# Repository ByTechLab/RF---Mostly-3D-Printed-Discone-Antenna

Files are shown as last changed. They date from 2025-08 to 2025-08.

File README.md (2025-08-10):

<div align="center">
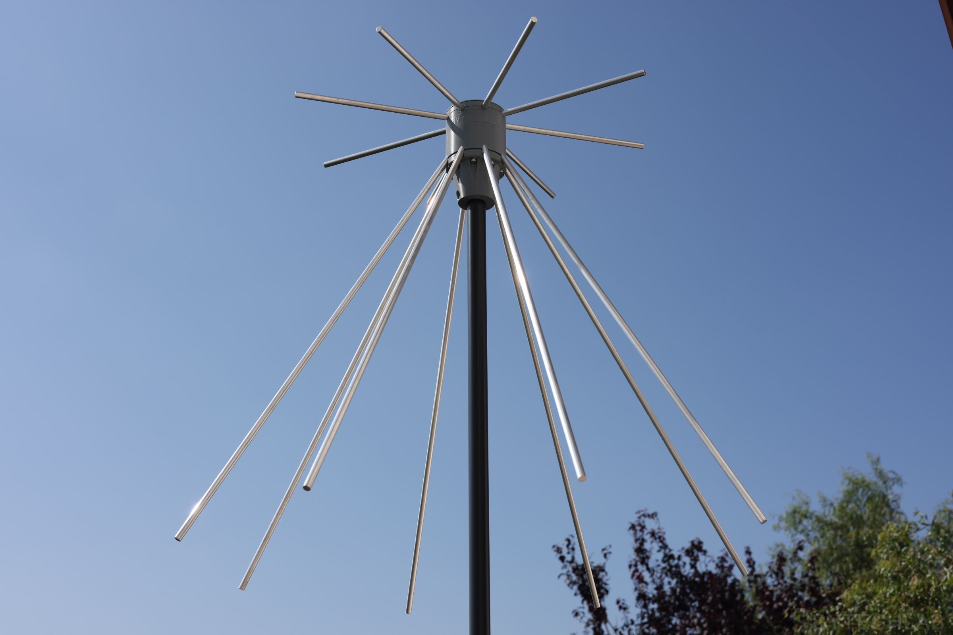
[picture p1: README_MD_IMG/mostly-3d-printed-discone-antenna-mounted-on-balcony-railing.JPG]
project photo
    
</div>

Mostly 3D printed discone antenna for Software Definied Radio.

### Read more at BYTECHLAB:

<table style="width: 100%; border: none;" cellspacing="0" cellpadding="0" border="0">
  <tr>
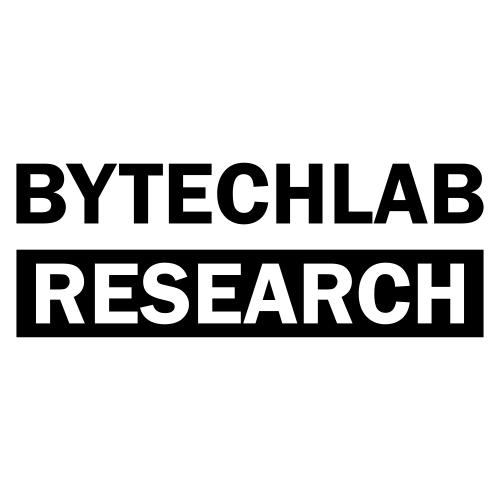
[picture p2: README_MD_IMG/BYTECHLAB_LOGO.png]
    <td></td>
    <td>https://bytechlab.com/2018/05/mostly-3d-printed-discone-antenna/</td>
  </tr>
</table>

## License
Software \ Firmware:



Hardware \ Hardware design files \ Hardware documentation:

[][cc-by-nc-sa]

[Creative Commons Attribution-NonCommercial-ShareAlike 4.0 International License][cc-by-nc-sa].

[][cc-by-nc-sa]

[cc-by-nc-sa]: http://creativecommons.org/licenses/by-nc-sa/4.0/
[cc-by-nc-sa-image]: https://licensebuttons.net/l/by-nc-sa/4.0/88x31.png
[cc-by-nc-sa-shield]: https://img.shields.io/badge/License-CC%20BY--NC--SA%204.0-lightgrey.svg

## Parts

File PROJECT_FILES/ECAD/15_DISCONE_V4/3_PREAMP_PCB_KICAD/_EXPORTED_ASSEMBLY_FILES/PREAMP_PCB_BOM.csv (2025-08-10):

Reference | Qty | Manufacturer | Manufacturer Part Number | SCH_FOOTPRINT
C1,C4 | 2 | Wurth Elektronik | 885012206052 | 0603
C2,C3 | 2 | Kemet | C0603X104K1RACTU | 0603
C5,C6 | 2 | Murata | GRM1885C1H103JA01D | 0603
GDT1,GDT2 | 2 | Littelfuse | CG775MS | 2.8x3.5mm
J1,J2 | 2 | Adam Tech | RF2-143-T-17-50-G | SMA_EDGE
L1 | 1 | Murata Electronics | LQW18ANR39J00D | 0603
L2,L3 | 2 | Coilcraft | WA8514-AE | 4.4x2mm
R1 | 1 | Panasonic | ERJ-3EKF1001V | 0603
TVS1,TVS2 | 2 | Bourns | CGA0603MLC-05E | 0603
U1 | 1 | ON Semiconductor | NCV8163ASN300T1G | SOT23-5
U2 | 1 | Mini-Circuits | PMA-5452+ | DQ849

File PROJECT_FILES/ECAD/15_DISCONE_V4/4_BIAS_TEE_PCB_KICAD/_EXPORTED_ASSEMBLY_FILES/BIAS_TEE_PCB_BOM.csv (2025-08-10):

Reference | Qty | Manufacturer | Manufacturer Part Number | SCH_FOOTPRINT
C1 | 1 | Kemet | C0603X104K1RACTU | 0603
C2 | 1 | Wurth Elektronik | 885012206052 | 0603
C3,C4 | 2 | Murata | GRM155R71H104KE14D | 0402
C5 | 1 | Murata | GRM1885C1H103JA01D | 0603
F1 | 1 | BEL Fuse | 0ZCJ0025AF2E | 1206
GDT1 | 1 | Littelfuse | CG775MS | 2.8x3.5mm
J1 | 1 | GCT | USB4105-GF-A | SMD USBC
J2 | 1 | Amphenol RF | 132366 | SMA_EDGE
J3 | 1 | Adam Tech | RF2-143-T-17-50-G | SMA_EDGE
L1 | 1 | Coilcraft | WA8514-AE | 4.4x2mm
R1,R2 | 2 | Panasonic | ERJ-2RKF5101X | 0402
R3,R4 | 2 | Panasonic | ERJ-2RKF1004X | 0402
TVS1 | 1 | Bourns | CGA0603MLC-05E | 0603

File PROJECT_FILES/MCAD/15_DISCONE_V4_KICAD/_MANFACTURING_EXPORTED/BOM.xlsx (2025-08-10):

Item | Filename | Thumbnail | BOM Structure | Unit QTY | QTY
1 | 3DP_ASA_Top_Disc_Bottom_Half.ipt |  | Normal | Each | 1
2 | CUT_COPPER_Top_Disc_1,5mm_Connecting_Wire.ipt |  | Normal | Each | 8
3 | ISO 7380-1 - M4 x 10.ipt |  | Purchased | Each | 16
4 | CUT_ALU_10x284mm_Rod.ipt |  | Normal | Each | 8
5 | 3DP_ASA_Rod_End_Cap.ipt |  | Normal | Each | 16
6 | 3DP_ASA_Top_Disc_Top_Half.ipt |  | Normal | Each | 1
7 | 3DP_ASA_Bottom_Cone_Bottom_Half.ipt |  | Normal | Each | 1
8 | 3DP_ASA_Bottom_Cone_Top_Half.ipt |  | Normal | Each | 1
9 | CUT_ALU_10x800mm_Rod.ipt |  | Normal | Each | 8
10 | CUT_COPPER_Bottom_Cone_1,5mm_Connecting_Wire.ipt |  | Normal | Each | 8
11 | CUT_FR4_Bottom_Cone_PCB.ipt |  | Purchased | Each | 1
12 | COTS_CarbonCenter_Fiberglass_30x28x2000mm_Pipe.ipt |  | Normal | Each | 1
13 | 3DP_ASA_Mast_Mount.ipt |  | Normal | Each | 1
14 | 3DP_ASA_Cone_and_Disc_Mount.ipt |  | Normal | Each | 1
15 | DIN 934 - M5 x 0,8.ipt |  | Purchased | Each | 15
16 | DIN 125 - A 5,3.ipt |  | Purchased | Each | 22
17 | COTS_GENERIC_DIN 912 - M5x80.ipt |  | Purchased | Each | 8
18 | COTS_Dremec_8G206M5X40_M5x40_Nylon_Screw.ipt |  | Purchased | Each | 8
19 | COTS_GENERIC_DIN 912 - M5x60.ipt |  | Purchased | Each | 1
20 | 3DP_ASA_Balcony_Mounting_Clamp_Back.ipt |  | Normal | Each | 3
21 | 3DP_ASA_Balcony_Mounting_Clamp_Front.ipt |  | Normal | Each | 3
22 | 3DP_ASA_Balcony_Mounting_Clamp_Mid.ipt |  | Normal | Each | 3
23 | COTS_GENERIC_DIN 912 - M5x120.ipt |  | Purchased | Each | 6
24 | COTS_GENERIC_Balcony_Railing.ipt |  | Normal | Each | 1
25 | 3DP_ASA_Preamp_Case_Bottom.ipt |  | Normal | Each | 1
26 | COTS_BOSSARD_1386867_M3_Insert.ipt |  | Normal | Each | 8
27 | 3DP_ASA_Preamp_Case_Top.ipt |  | Normal | Each | 1
28 | DIN 125 - A 3,2.ipt |  | Purchased | Each | 8
29 | ISO 7380-1 - M3 x 16.ipt |  | Purchased | Each | 4
30 | 3DP_ASA_Preamp_Case_Clamp.ipt |  | Normal | Each | 1
31 | DIN 125 - A 4,3.ipt |  | Purchased | Each | 2
32 | COTS_GENERIC_DIN 912 - M4x50.ipt |  | Purchased | Each | 2
33 | DIN 934 - M4 x 0,7.ipt |  | Purchased | Each | 2
34 | 3DP_ASA_Bias_Tee_Case_Bottom.ipt |  | Normal | Each | 1
35 | 3DP_ASA_Bias_Tee_Case_Top.ipt |  | Normal | Each | 1
36 | ISO 7380-1 - M3 x 12.ipt |  | Purchased | Each | 4
37 | ASSEMBLY_PREAMP_PCB.iam |  | Purchased | Each | 1
38 | ASSEMBLY_BIAS_TEE_PCB.iam |  | Purchased | Each | 1
39 | COTS_Pasternack_RG58CU_Coax_Cable.iam |  | Purchased | Each | 1
40 | COTS_BOSSARD_B5_BN81_M5_Nylon_Nuts.ipt |  | Purchased | Each | 8

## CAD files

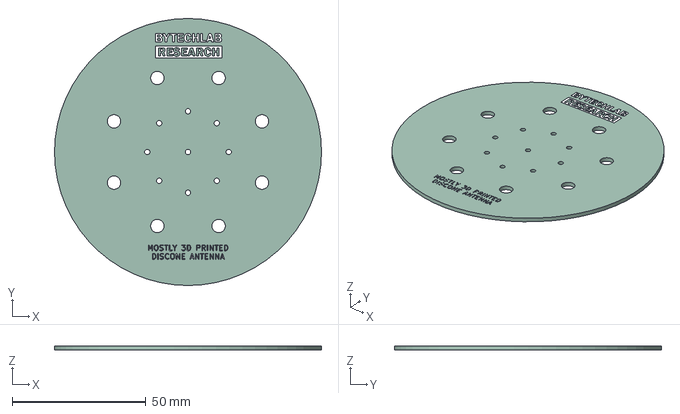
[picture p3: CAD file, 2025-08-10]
PROJECT_FILES/ECAD/15_DISCONE_V4/1_DISC_PCB_KICAD/_EXPORTED_STEP/DISC_PCB.step
100.0 x 100.0 x 1.58 mm
DISC_PCB_silkscreen
DISC_PCB_PCB

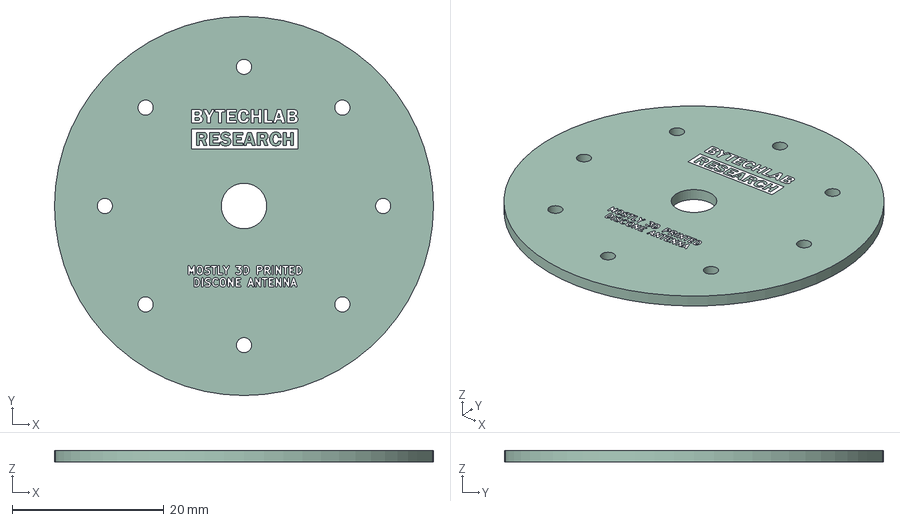
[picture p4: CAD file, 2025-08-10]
PROJECT_FILES/ECAD/15_DISCONE_V4/2_CONE_PCB_KICAD/_EXPORTED_STEP/CONE_PCB.step
50.0 x 50.0 x 1.58 mm
CONE_PCB_silkscreen
CONE_PCB_PCB

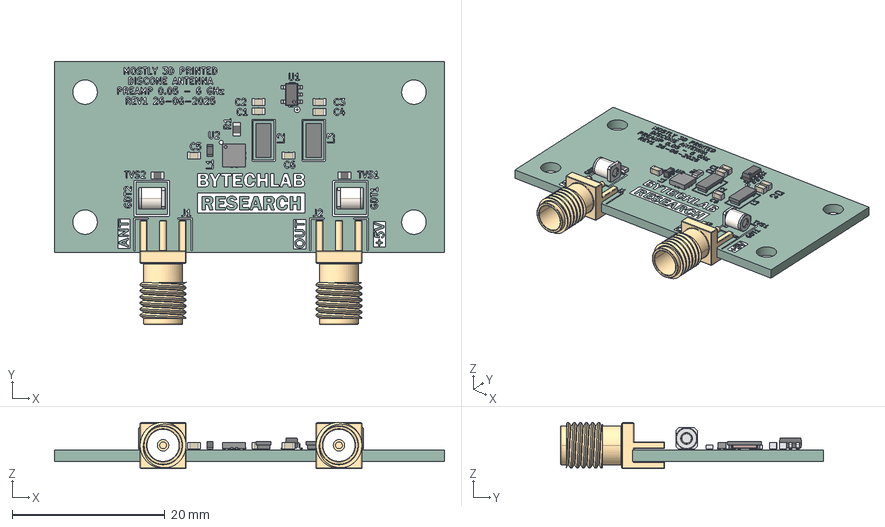
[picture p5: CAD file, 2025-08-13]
PROJECT_FILES/ECAD/15_DISCONE_V4/3_PREAMP_PCB_KICAD/_EXPORTED_STEP/PREAMP_PCB.step
51.0 x 34.4 x 6.05 mm
kicad_embedded_AF53ECB398E4EB83F4DB7513C7E66ADB x 2
kicad_embedded_58FAB470A1E653965DBA7634B3A30C80 x 6
kicad_embedded_1C9C9A1E310F6A3E4F7E73613D0DE863 x 2
ThermalPin
PinsArrayLR
PinsArrayTB
kicad_embedded_97E8DD9E3C95D06D5F928557DB7F59B4 x 2
kicad_embedded_E3F4CA87D5B743FA4485FD5496ABCF2D x 3
Rect1
Rect2
Rect3
Rect4
Rect5
Rect6
Rect7
Rect8
Rect9
Rect10
Rect11
Rect12
Rect13
Rect14
Rect15
Rect16
Rect17
kicad_embedded_CC80B7AC80E2613677E769BE56643C0D
PREAMP_PCB_silkscreen
PREAMP_PCB_PCB

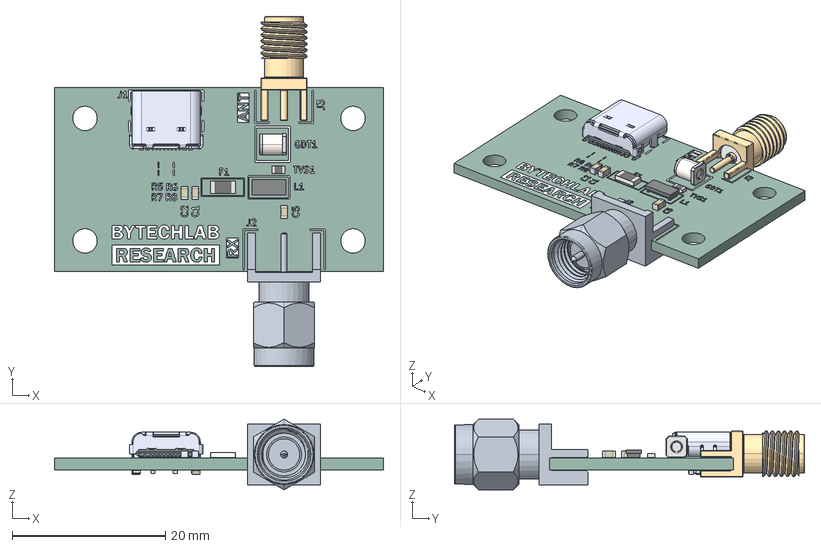
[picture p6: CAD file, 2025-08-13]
PROJECT_FILES/ECAD/15_DISCONE_V4/4_BIAS_TEE_PCB_KICAD/_EXPORTED_STEP/BIAS_TEE_PCB.step
43.0 x 45.7 x 9.24 mm
kicad_embedded_C749484239B3140A542284B6F6FFB23F
USB4105
kicad_embedded_58FAB470A1E653965DBA7634B3A30C80 x 3
kicad_embedded_AF53ECB398E4EB83F4DB7513C7E66ADB
kicad_embedded_97E8DD9E3C95D06D5F928557DB7F59B4
kicad_embedded_E3F4CA87D5B743FA4485FD5496ABCF2D
kicad_embedded_B4BB7D874C438E7417D3FB72FE57B8BC
kicad_embedded_1C9C9A1E310F6A3E4F7E73613D0DE863
Mid_Body x 4
Mark x 4
kicad_embedded_655590AEAB6E99CB1BD85F3F82B6982D x 2
BIAS_TEE_PCB_silkscreen
BIAS_TEE_PCB_PCB

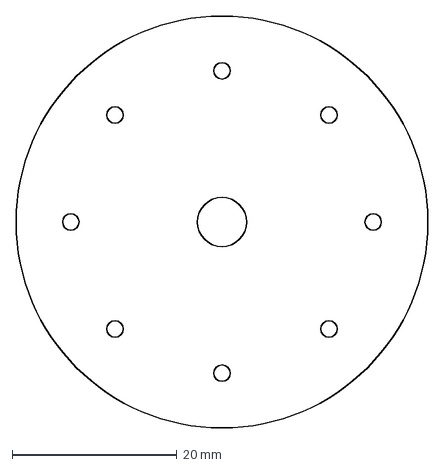
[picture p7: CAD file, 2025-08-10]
PROJECT_FILES/MCAD/15_DISCONE_V4_KICAD/_DXF_EXPORTED/CUT_FR4_Bottom_Cone_PCB.dxf
50.0 x 50.0 mm

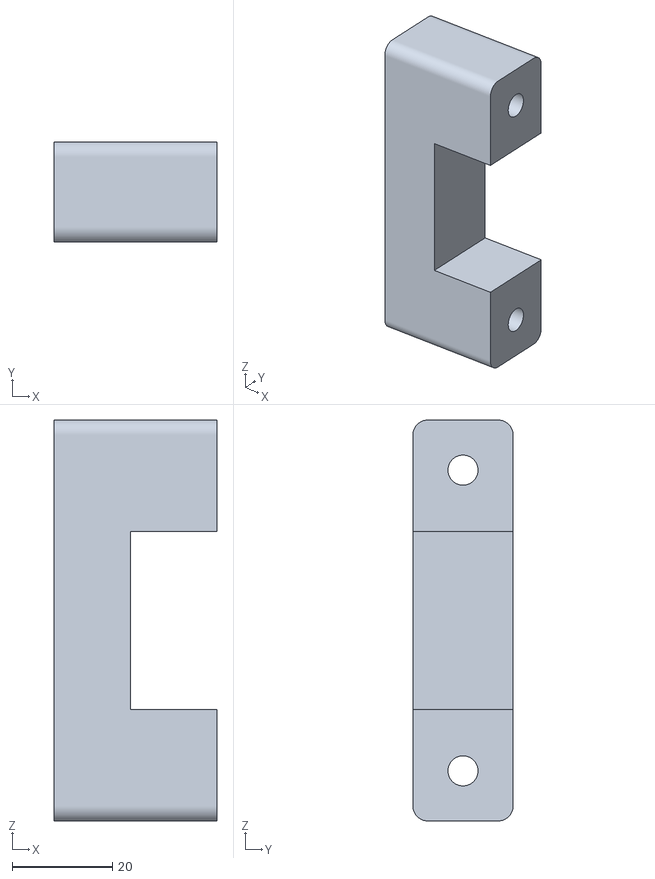
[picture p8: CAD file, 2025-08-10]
PROJECT_FILES/MCAD/15_DISCONE_V4_KICAD/_STL_EXPORTED/3DP_ASA_Balcony_Mounting_Clamp_Back.stl
32.5 x 20.0 x 80.0

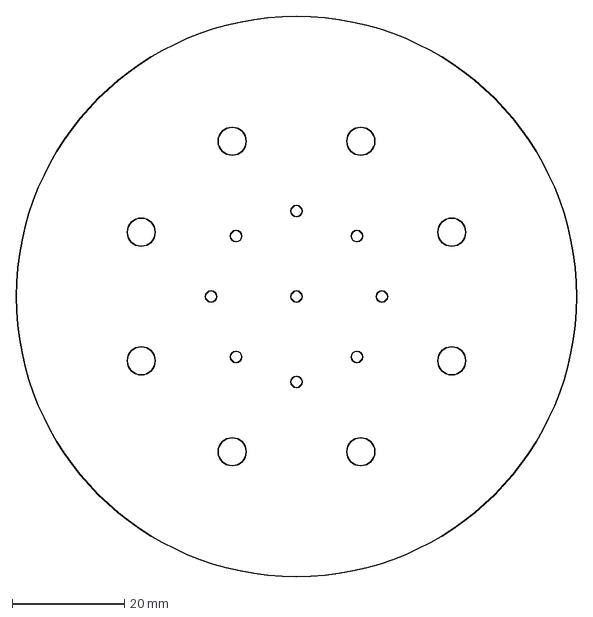
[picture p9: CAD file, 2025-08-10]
PROJECT_FILES/MCAD/15_DISCONE_V4_KICAD/_DXF_EXPORTED/CUT_FR4_Top_Disc_PCB.dxf
100.0 x 100.0 mm

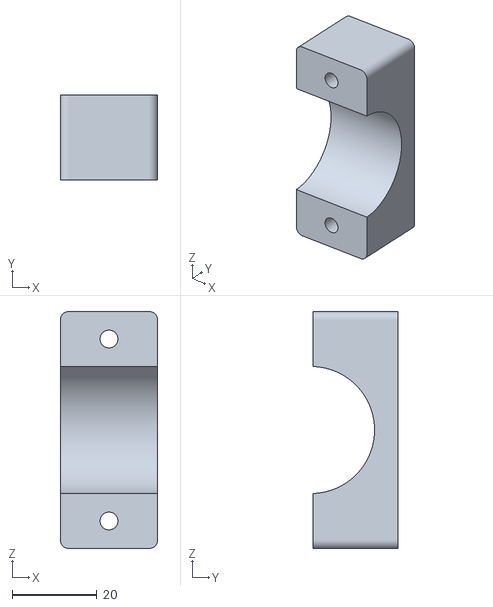
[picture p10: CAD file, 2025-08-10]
PROJECT_FILES/MCAD/15_DISCONE_V4_KICAD/_STL_EXPORTED/3DP_ASA_Preamp_Case_Clamp.stl
23.0 x 20.0 x 56.0

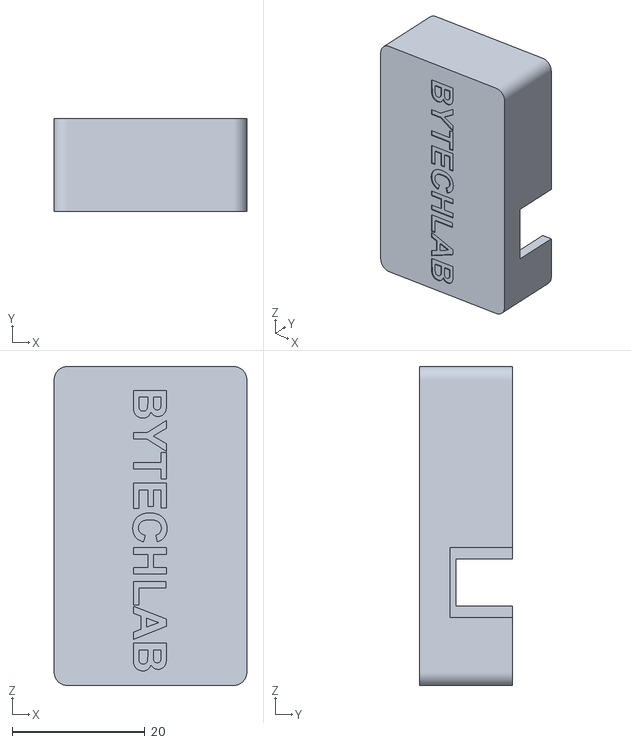
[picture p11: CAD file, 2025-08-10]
PROJECT_FILES/MCAD/15_DISCONE_V4_KICAD/_STL_EXPORTED/3DP_ASA_Bias_Tee_Case_Bottom.stl
29.0 x 14.0 x 48.0

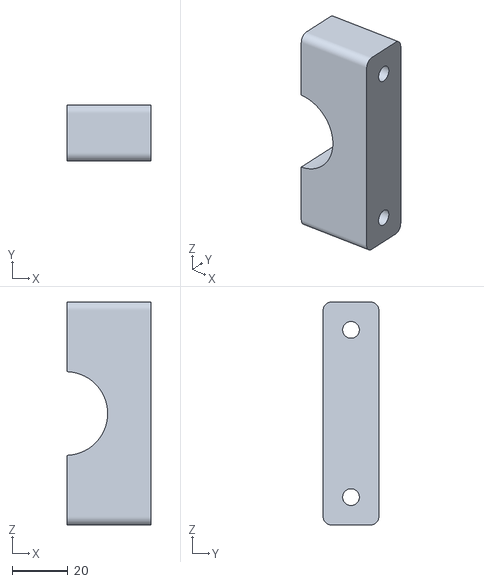
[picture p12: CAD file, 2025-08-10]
PROJECT_FILES/MCAD/15_DISCONE_V4_KICAD/_STL_EXPORTED/3DP_ASA_Balcony_Mounting_Clamp_Front.stl
30.0 x 20.0 x 80.0

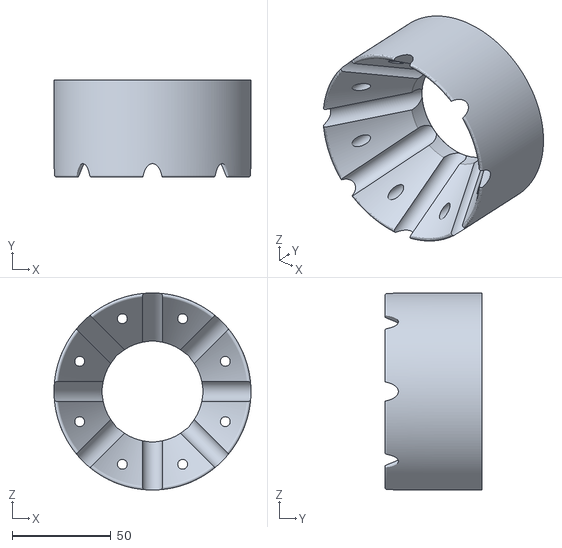
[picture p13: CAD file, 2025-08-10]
PROJECT_FILES/MCAD/15_DISCONE_V4_KICAD/_STL_EXPORTED/3DP_ASA_Bottom_Cone_Top_Half.stl
100.0 x 49.2 x 100.0

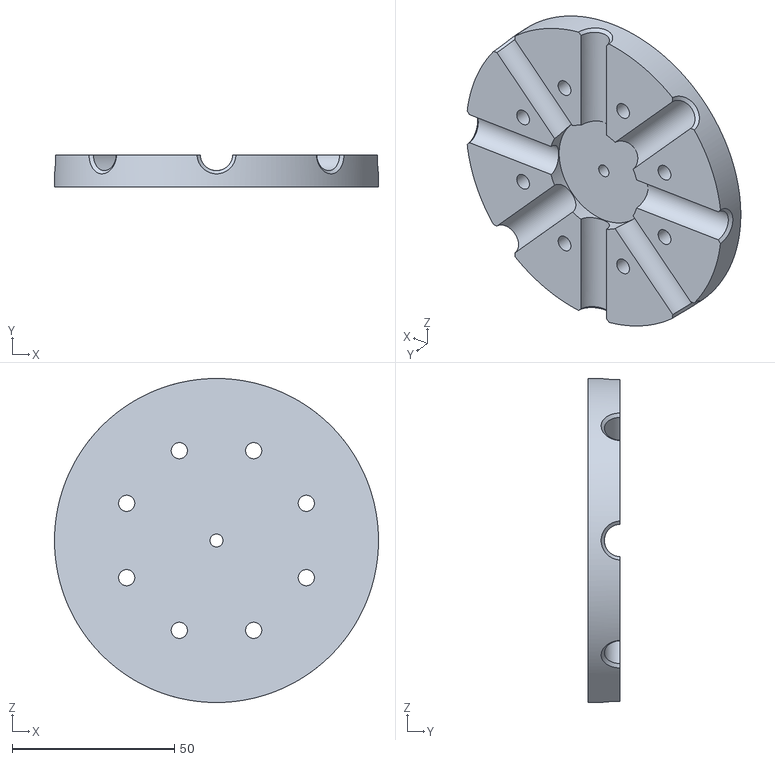
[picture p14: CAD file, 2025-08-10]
PROJECT_FILES/MCAD/15_DISCONE_V4_KICAD/_STL_EXPORTED/3DP_ASA_Top_Disc_Bottom_Half.stl
100.0 x 9.75 x 100.0

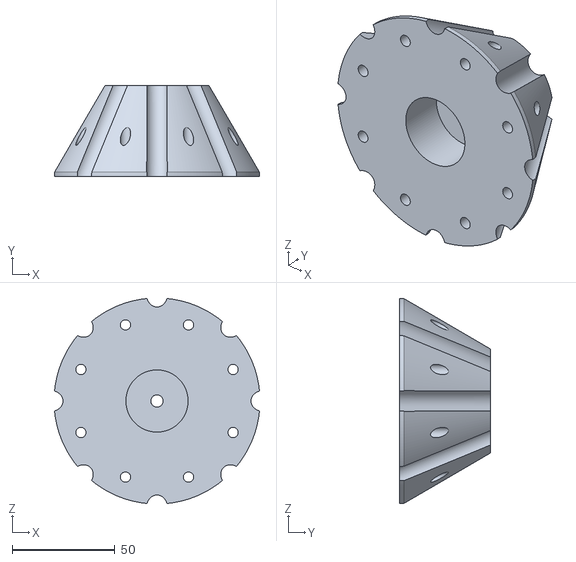
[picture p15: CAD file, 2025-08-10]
PROJECT_FILES/MCAD/15_DISCONE_V4_KICAD/_STL_EXPORTED/3DP_ASA_Bottom_Cone_Bottom_Half.stl
99.5 x 44.0 x 99.5

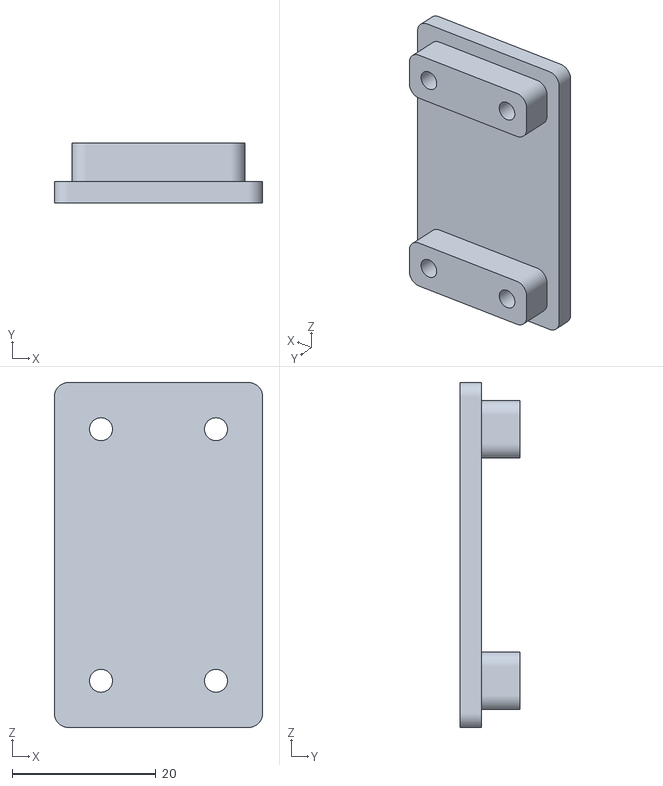
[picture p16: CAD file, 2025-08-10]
PROJECT_FILES/MCAD/15_DISCONE_V4_KICAD/_STL_EXPORTED/3DP_ASA_Bias_Tee_Case_Top.stl
29.0 x 8.35 x 48.0

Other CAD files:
PROJECT_FILES/MCAD/15_DISCONE_V4_KICAD/__KICAD_PCB_PARTS/3_PREAMP_PCB/PREAMP_PCB.step
PROJECT_FILES/MCAD/15_DISCONE_V4_KICAD/__KICAD_PCB_PARTS/4_BIAS_TEE_PCB/BIAS_TEE_PCB.step
PROJECT_FILES/MCAD/15_DISCONE_V4_KICAD/_STL_EXPORTED/3DP_ASA_Mast_Mount.stl
PROJECT_FILES/MCAD/15_DISCONE_V4_KICAD/_STL_EXPORTED/3DP_ASA_Cone_and_Disc_Mount.stl
PROJECT_FILES/MCAD/15_DISCONE_V4_KICAD/ASSEMBLY_BIAS_TEE_REVA/3DP_ASA_Bias_Tee_Case_Bottom.ipt
PROJECT_FILES/MCAD/15_DISCONE_V4_KICAD/ASSEMBLY_BIAS_TEE_REVA/3DP_ASA_Bias_Tee_Case_Top.ipt
PROJECT_FILES/MCAD/15_DISCONE_V4_KICAD/ASSEMBLY_BIAS_TEE_REVA/ASSEMBLY_Bias_Tee.iam
PROJECT_FILES/MCAD/15_DISCONE_V4_KICAD/ASSEMBLY_MAIN_REVA/3DP_ASA_Balcony_Mounting_Clamp_Back.ipt
PROJECT_FILES/MCAD/15_DISCONE_V4_KICAD/ASSEMBLY_MAIN_REVA/3DP_ASA_Balcony_Mounting_Clamp_Front.ipt
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

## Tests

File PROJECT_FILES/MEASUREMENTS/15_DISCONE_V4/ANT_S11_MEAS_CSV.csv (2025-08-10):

Frequency | S11_Magnitude
1000000 | 0.05513519296
2333111 | 0.02341437824
3666222 | -0.02137758811
4999333 | -0.02236590339
6332444 | -0.05546119686
7665555 | -0.08383498702
8998666 | -0.1189489546
10331777 | -0.1857265506
11664888 | -0.2798246935
12998000 | -0.469047034
14331111 | -1.48108998
15664222 | -0.5898512326
16997333 | -0.4083073103
18330444 | -0.4161061288
19663555 | -0.4539049102
20996666 | -0.5099074856
22329777 | -0.6052676852
23662888 | -0.8539394178
24996000 | -1.334352746
26329111 | -0.9242038025
27662222 | -0.7388325187
28995333 | -0.6759752431
30328444 | -0.6866972922
31661555 | -0.7708385787
32994666 | -0.9649131307
34327777 | -1.376500829
35660888 | -1.507886541
36994000 | -1.061706854
38327111 | -0.8053189342
39660222 | -0.6883118722
40993333 | -0.6332555242
42326444 | -0.6055285822
43659555 | -0.6024546187
44992666 | -0.6099274539
46325777 | -0.6250206518
47658888 | -0.644331931
48992000 | -0.6698088453
50325111 | -0.6918566869
51658222 | -0.7191779765
52991333 | -0.7445692398
54324444 | -0.7657287771
55657555 | -0.788506958
56990666 | -0.8326555066
58323777 | -0.8776438637
59656888 | -0.9135615766
60990000 | -0.9903050306
62323111 | -1.068100004
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

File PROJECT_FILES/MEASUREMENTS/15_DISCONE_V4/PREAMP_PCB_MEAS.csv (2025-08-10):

Frequency | S11_Magnitude | S11_Phase | S12_Magnitude | S12_Phase | S21_Magnitude | S21_Phase | S22_Magnitude | S22_Phase
1000000 | -12.741019 | -130.0228258 | -70.53568211 | -110.3169254 | -6.450795048 | -76.98202246 | -40.25601045 | -170.6261754
4001000 | -15.94019528 | 157.038747 | -68.07557827 | 121.5521536 | -0.8167669241 | -131.5433993 | -42.3982682 | 93.92122077
7002001 | -15.01335552 | 124.1381173 | -62.33359039 | 88.59655483 | 0.6934578307 | -145.9385178 | -44.13963041 | 58.8808942
10003001 | -13.74677475 | 102.1839649 | -57.66190239 | 90.93916124 | 1.544488076 | -152.7678719 | -45.7232052 | 38.05092084
13004002 | -12.59954045 | 85.97083388 | -56.66241472 | 76.30839815 | 2.215357032 | -157.1608185 | -46.55862584 | 24.67293861
16005002 | -11.65511161 | 73.35523821 | -54.23063482 | 73.83929952 | 2.778324171 | -161.1315585 | -47.62093268 | 10.70388271
19006003 | -10.97941247 | 62.9797376 | -53.9384249 | 66.39923589 | 3.193159376 | -164.6841629 | -48.4659429 | -0.159831628
22007003 | -10.4931609 | 54.39422296 | -51.72418176 | 59.08658078 | 3.524235043 | -167.8310543 | -49.20098604 | -7.452064333
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

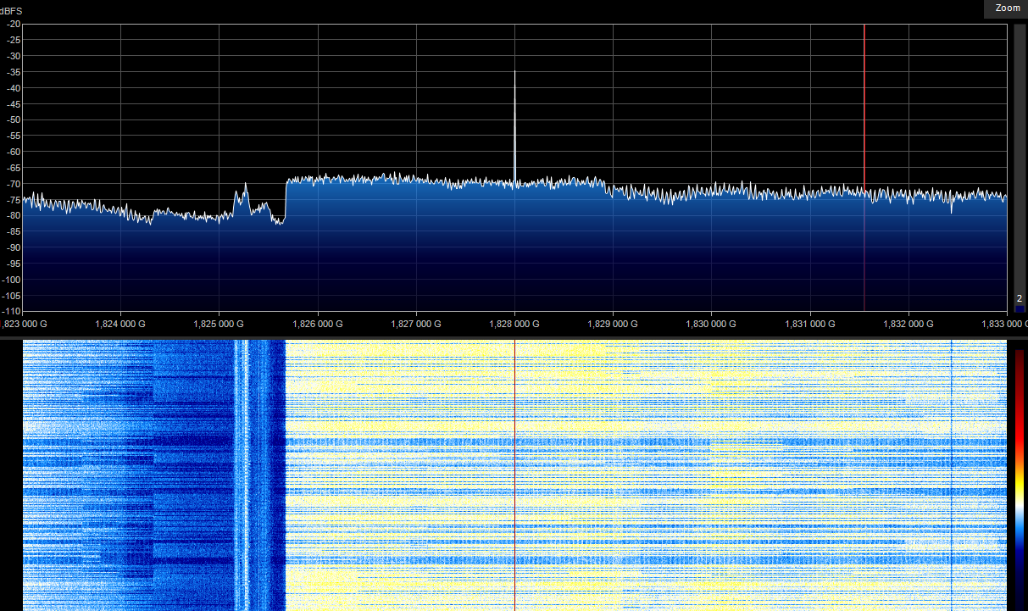
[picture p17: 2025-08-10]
PROJECT_FILES/MEASUREMENTS/15_DISCONE_V4/SDR_1800MHZ.png

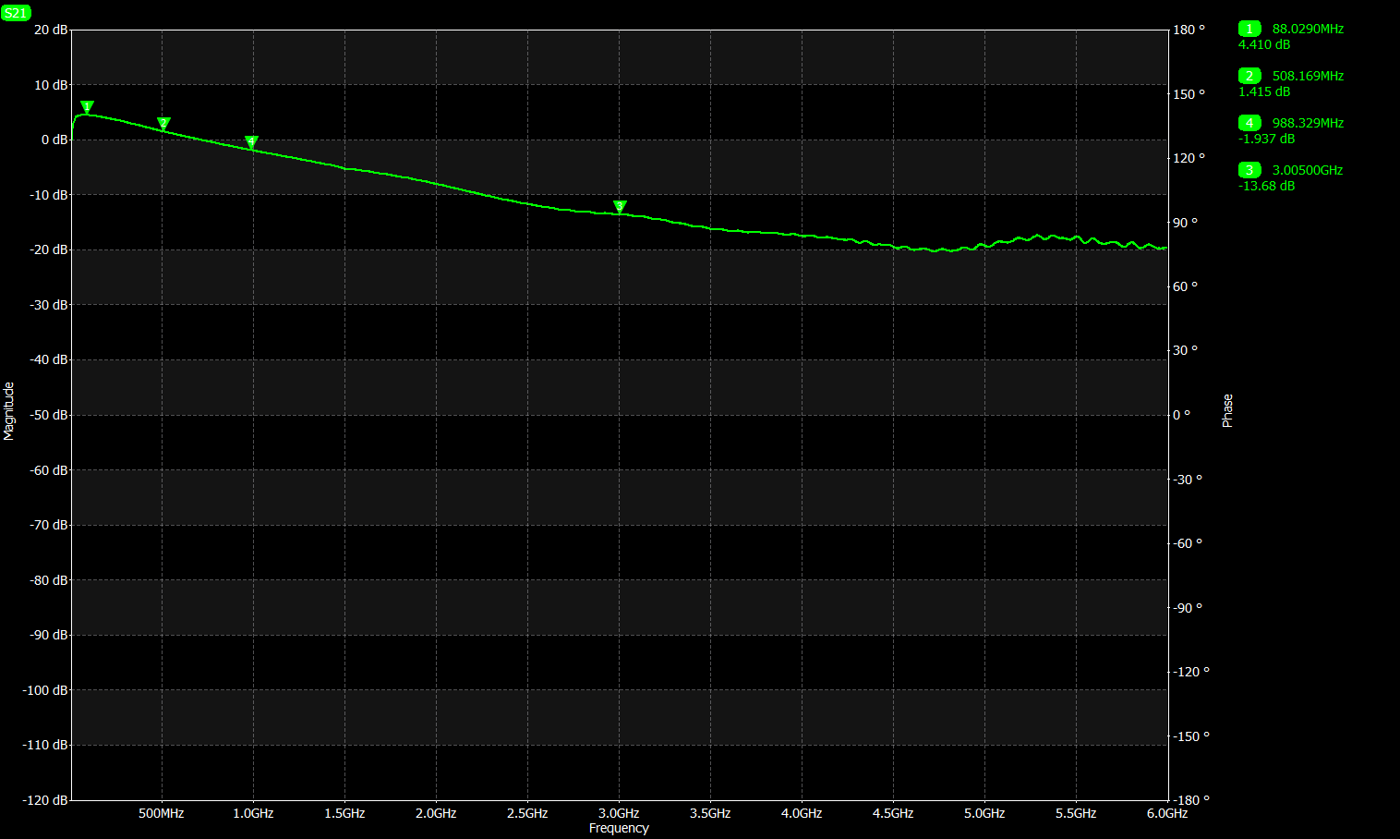
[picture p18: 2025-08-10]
PROJECT_FILES/MEASUREMENTS/15_DISCONE_V4/PREAMP_PCB_MEAS_S21_LOGMAG.png

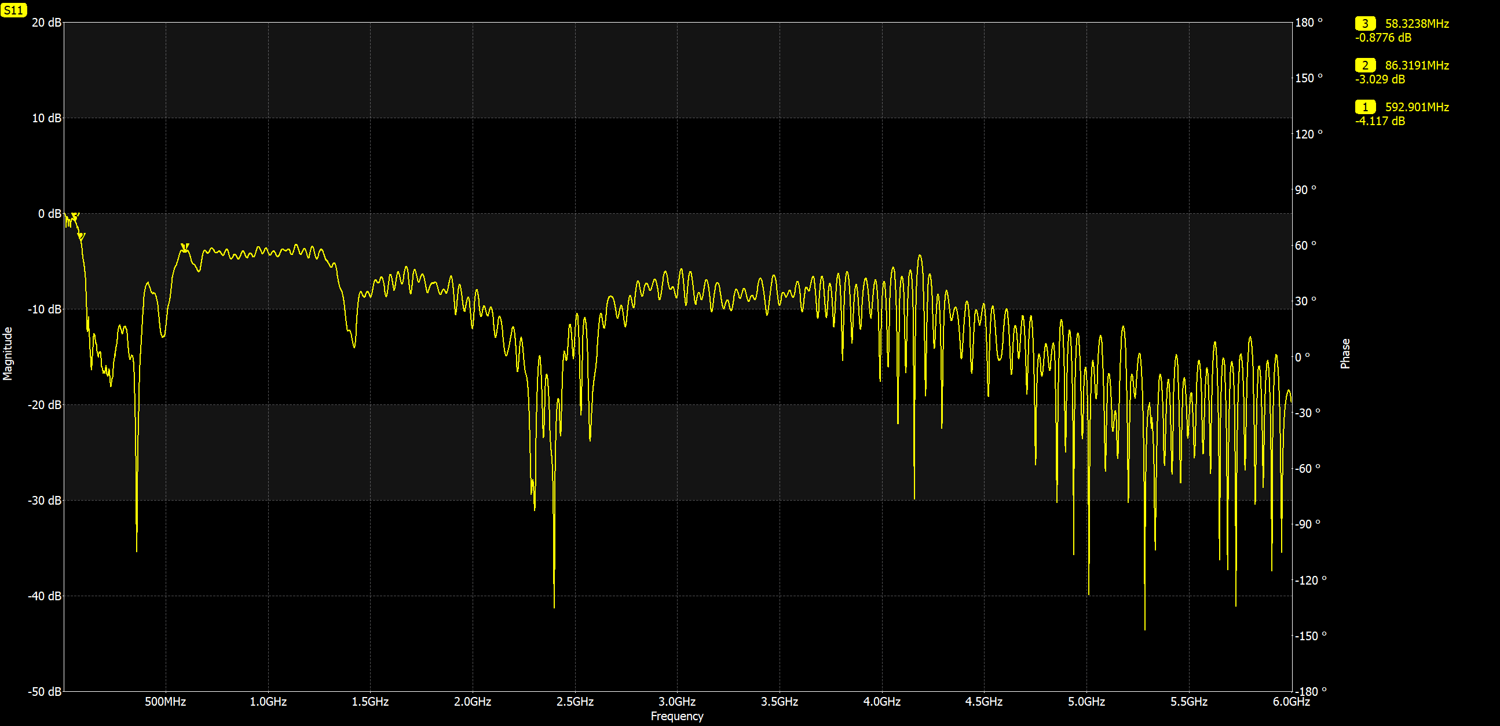
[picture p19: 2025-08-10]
PROJECT_FILES/MEASUREMENTS/15_DISCONE_V4/ANT_S11_LOGMAG.png

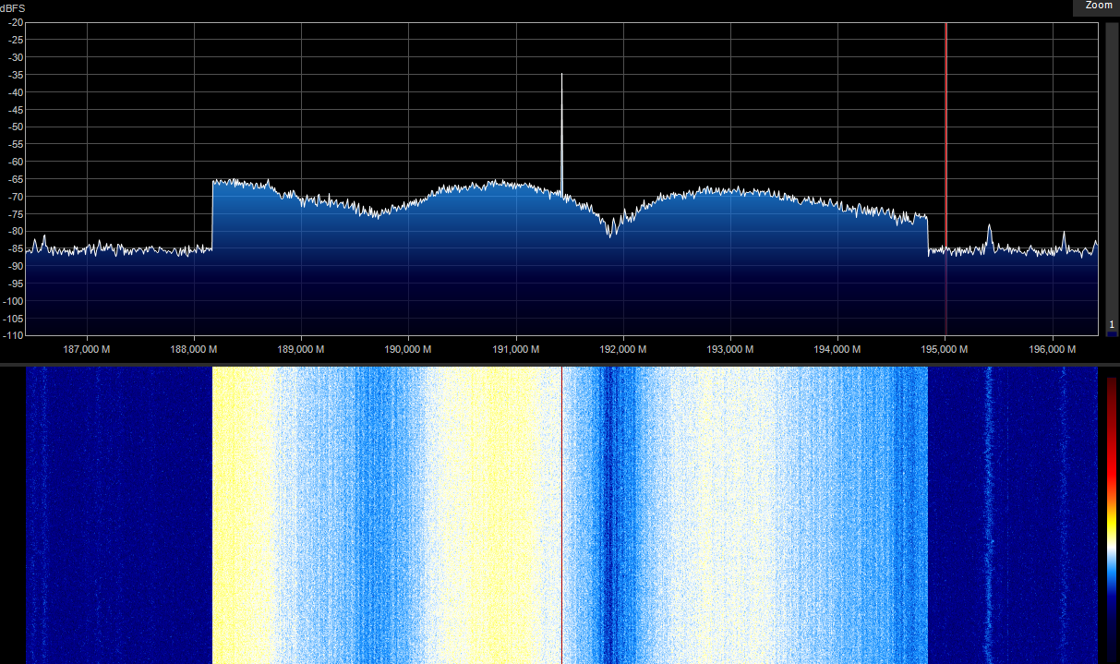
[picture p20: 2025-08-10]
PROJECT_FILES/MEASUREMENTS/15_DISCONE_V4/SDR_195MHZ.png

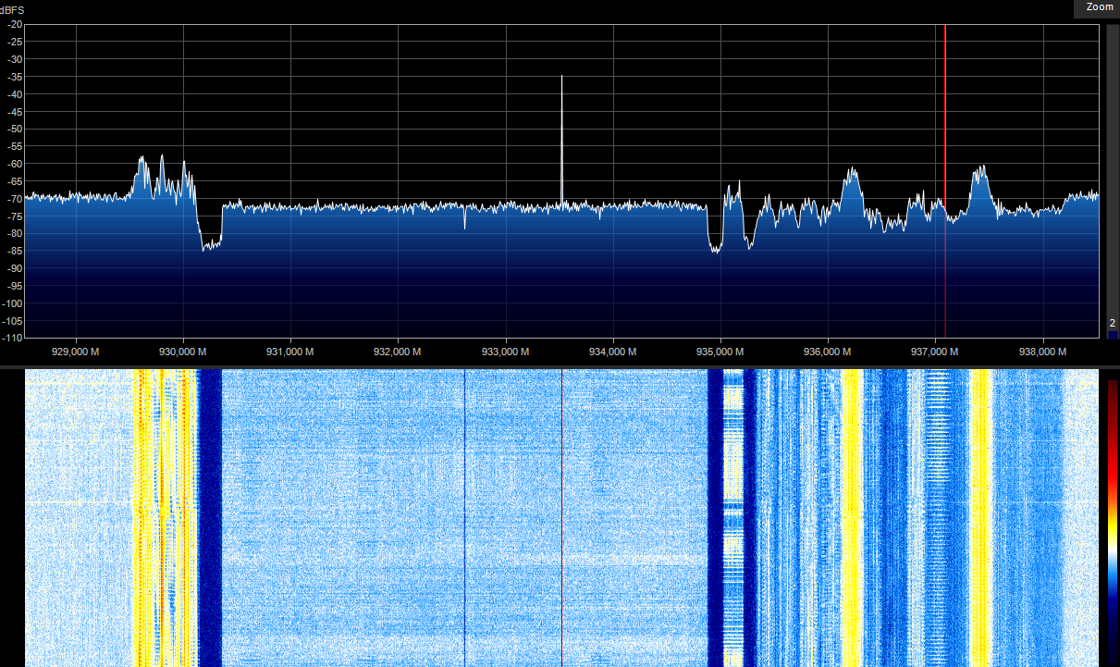
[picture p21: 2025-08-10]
PROJECT_FILES/MEASUREMENTS/15_DISCONE_V4/SDR_937MHZ.png

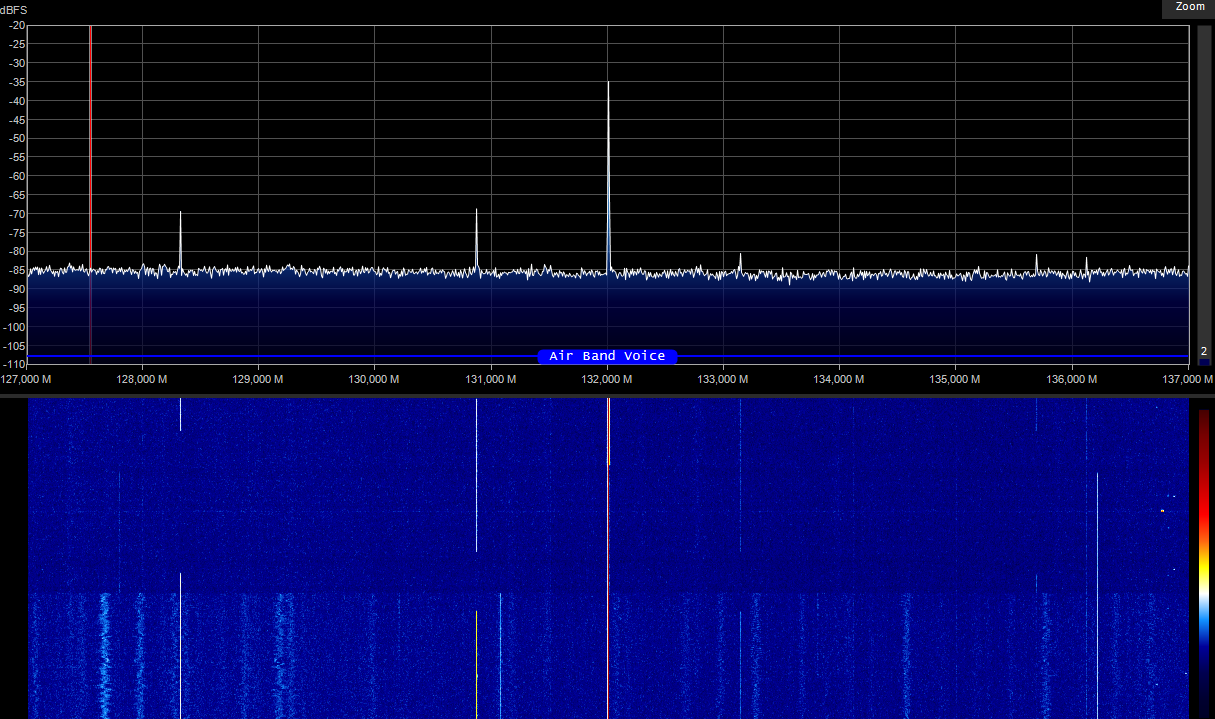
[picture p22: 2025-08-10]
PROJECT_FILES/MEASUREMENTS/15_DISCONE_V4/SDR_AIRBAND.png

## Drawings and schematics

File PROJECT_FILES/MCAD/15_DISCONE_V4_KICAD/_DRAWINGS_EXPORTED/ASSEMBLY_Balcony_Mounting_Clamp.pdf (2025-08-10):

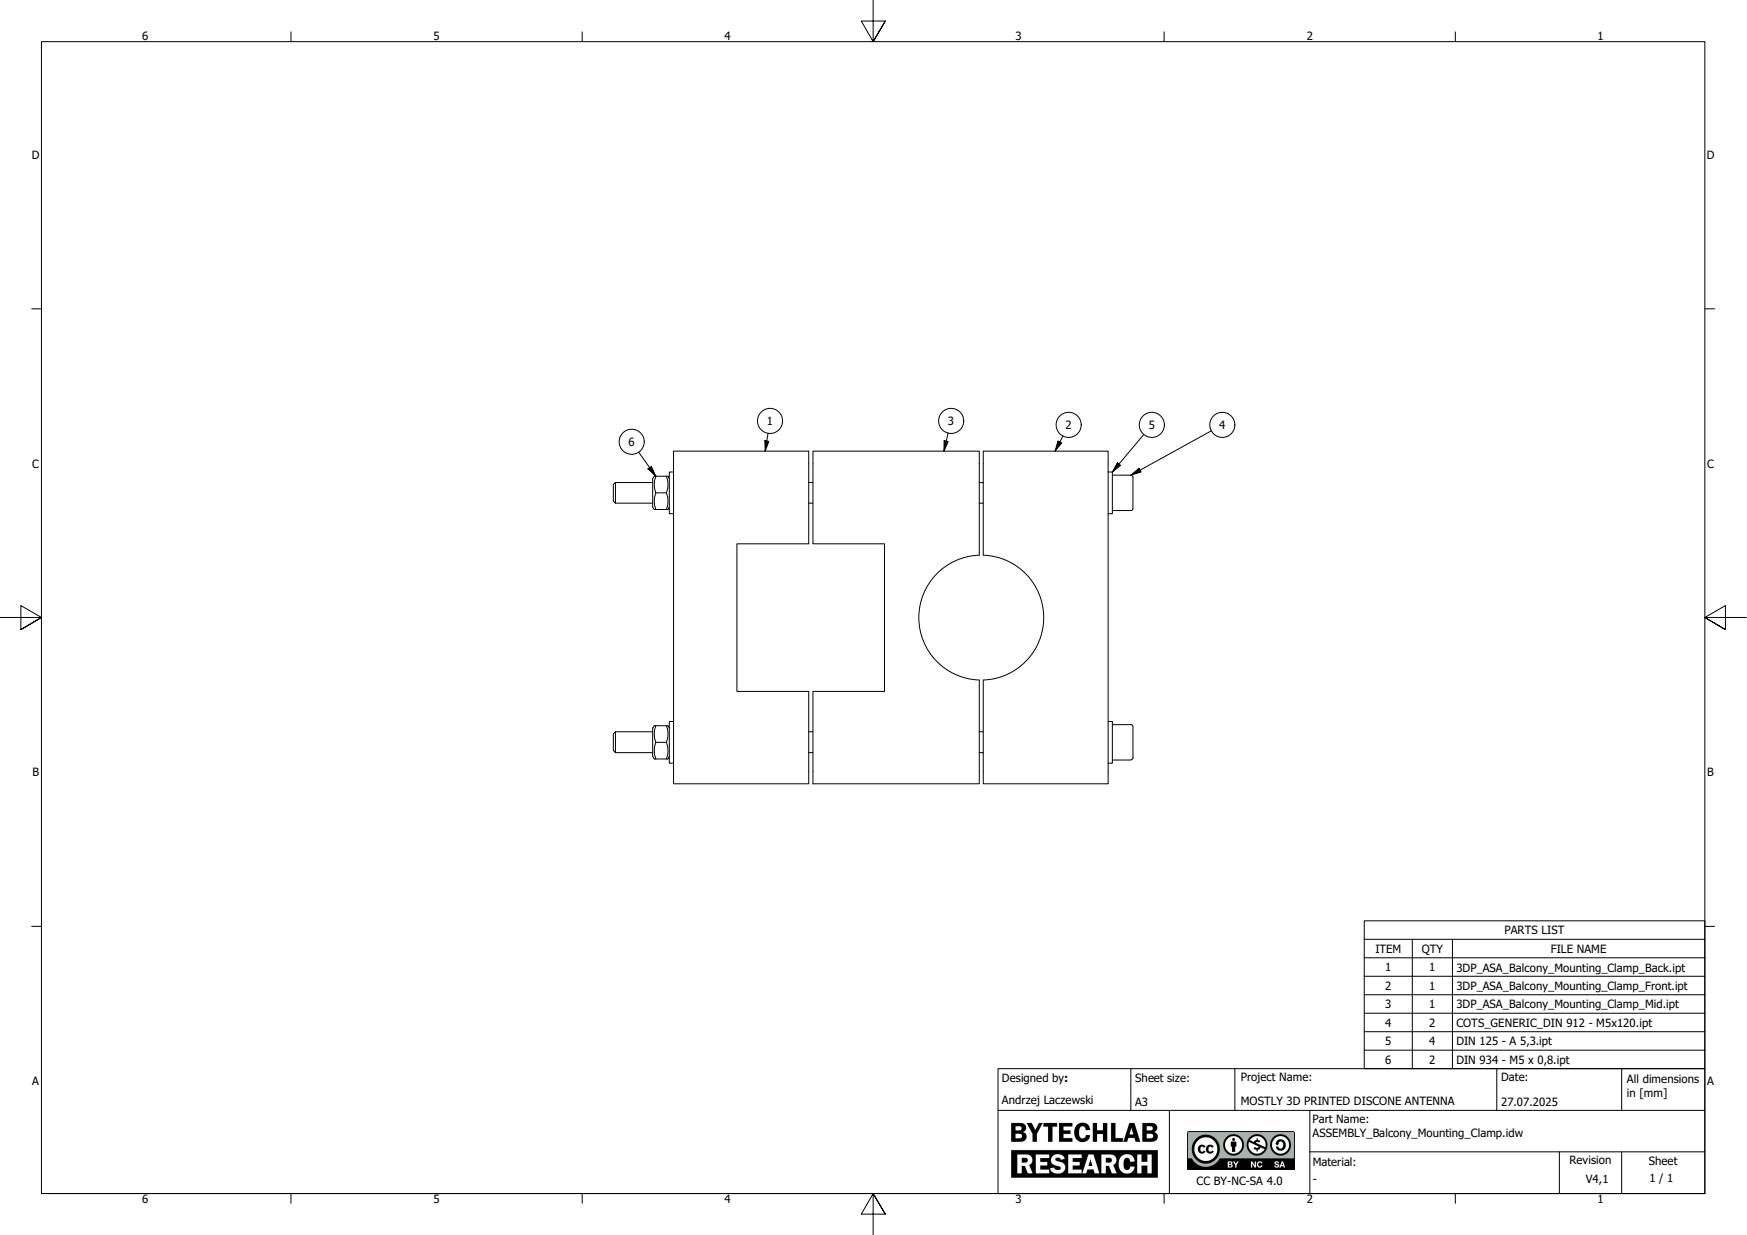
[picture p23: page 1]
PARTS LIST

ITEM | QTY | FILE NAME
1 | 1 | 3DP_ASA_Balcony_Mounting_Clamp_Back.ipt
2 | 1 | 3DP_ASA_Balcony_Mounting_Clamp_Front.ipt
3 | 1 | 3DP_ASA_Balcony_Mounting_Clamp_Mid.ipt
4 | 2 | COTS_GENERIC_DIN 912 - M5x120.ipt
5 | 4 | DIN 125 - A 5,3.ipt
6 | 2 | DIN 934 - M5 x 0,8.ipt

Designed by: Andrzej Laczewski | Sheet size: A3 | Project Name: MOSTLY 3D PRINTED DISCONE ANTENNA | Date: 27.07.2025 | All dimensions in [mm]

CC BY-NC-SA 4.0 | Part Name: ASSEMBLY_Balcony_Mounting_Clamp.idw

Material: - V4,1 | Revision | Sheet 1 / 1

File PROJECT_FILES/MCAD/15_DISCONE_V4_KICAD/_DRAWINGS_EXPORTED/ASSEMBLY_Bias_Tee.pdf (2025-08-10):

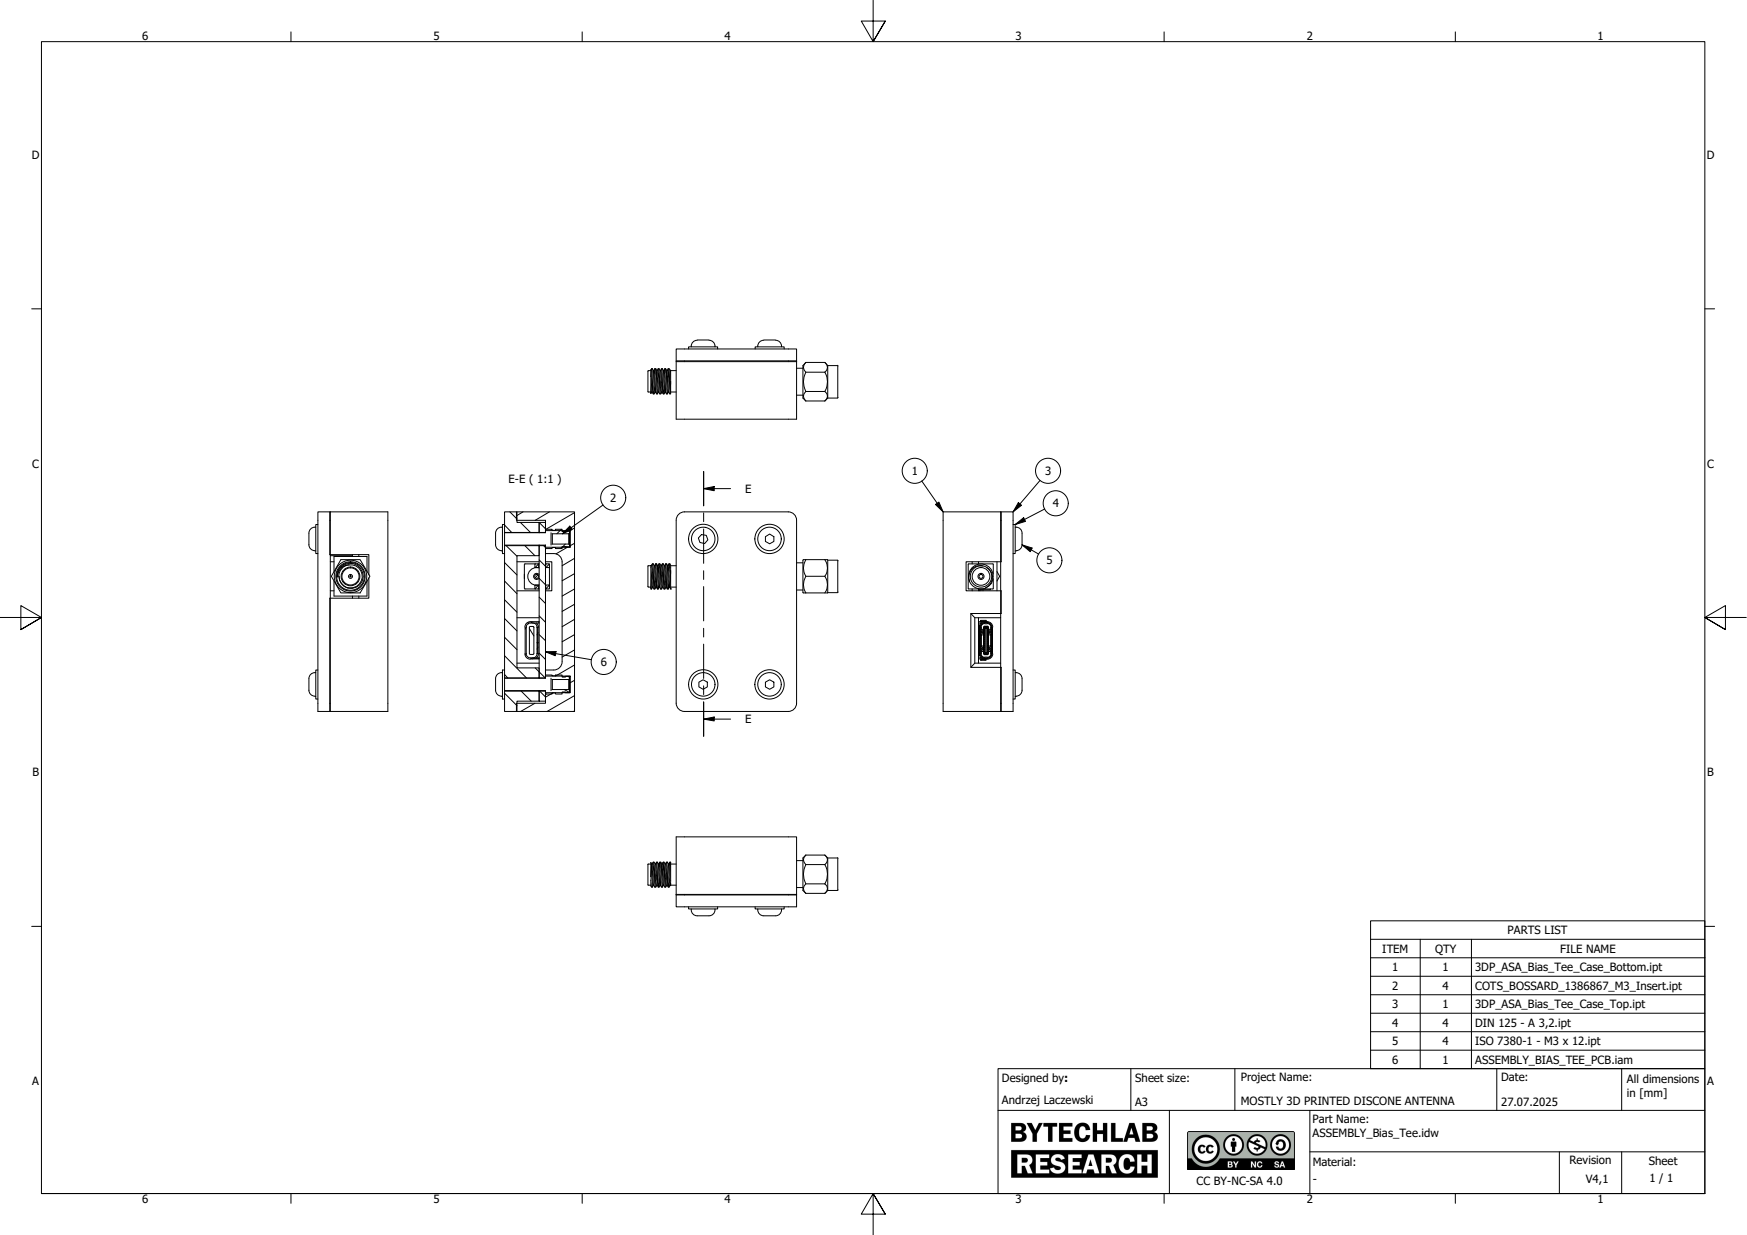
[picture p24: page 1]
PARTS LIST

ITEM | QTY | FILE NAME
1 | 1 | 3DP_ASA_Bias_Tee_Case_Bottom.ipt
2 | 4 | COTS_BOSSARD_1386867_M3_Insert.ipt
3 | 1 | 3DP_ASA_Bias_Tee_Case_Top.ipt
4 | 4 | DIN 125 - A 3,2.ipt
5 | 4 | ISO 7380-1 - M3 x 12.ipt
6 | 1 | ASSEMBLY_BIAS_TEE_PCB.iam

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

CC BY-NC-SA 4.0 | Part Name: ASSEMBLY_Bias_Tee.idw

Material: - V4,1 | Revision | Sheet 1 / 1

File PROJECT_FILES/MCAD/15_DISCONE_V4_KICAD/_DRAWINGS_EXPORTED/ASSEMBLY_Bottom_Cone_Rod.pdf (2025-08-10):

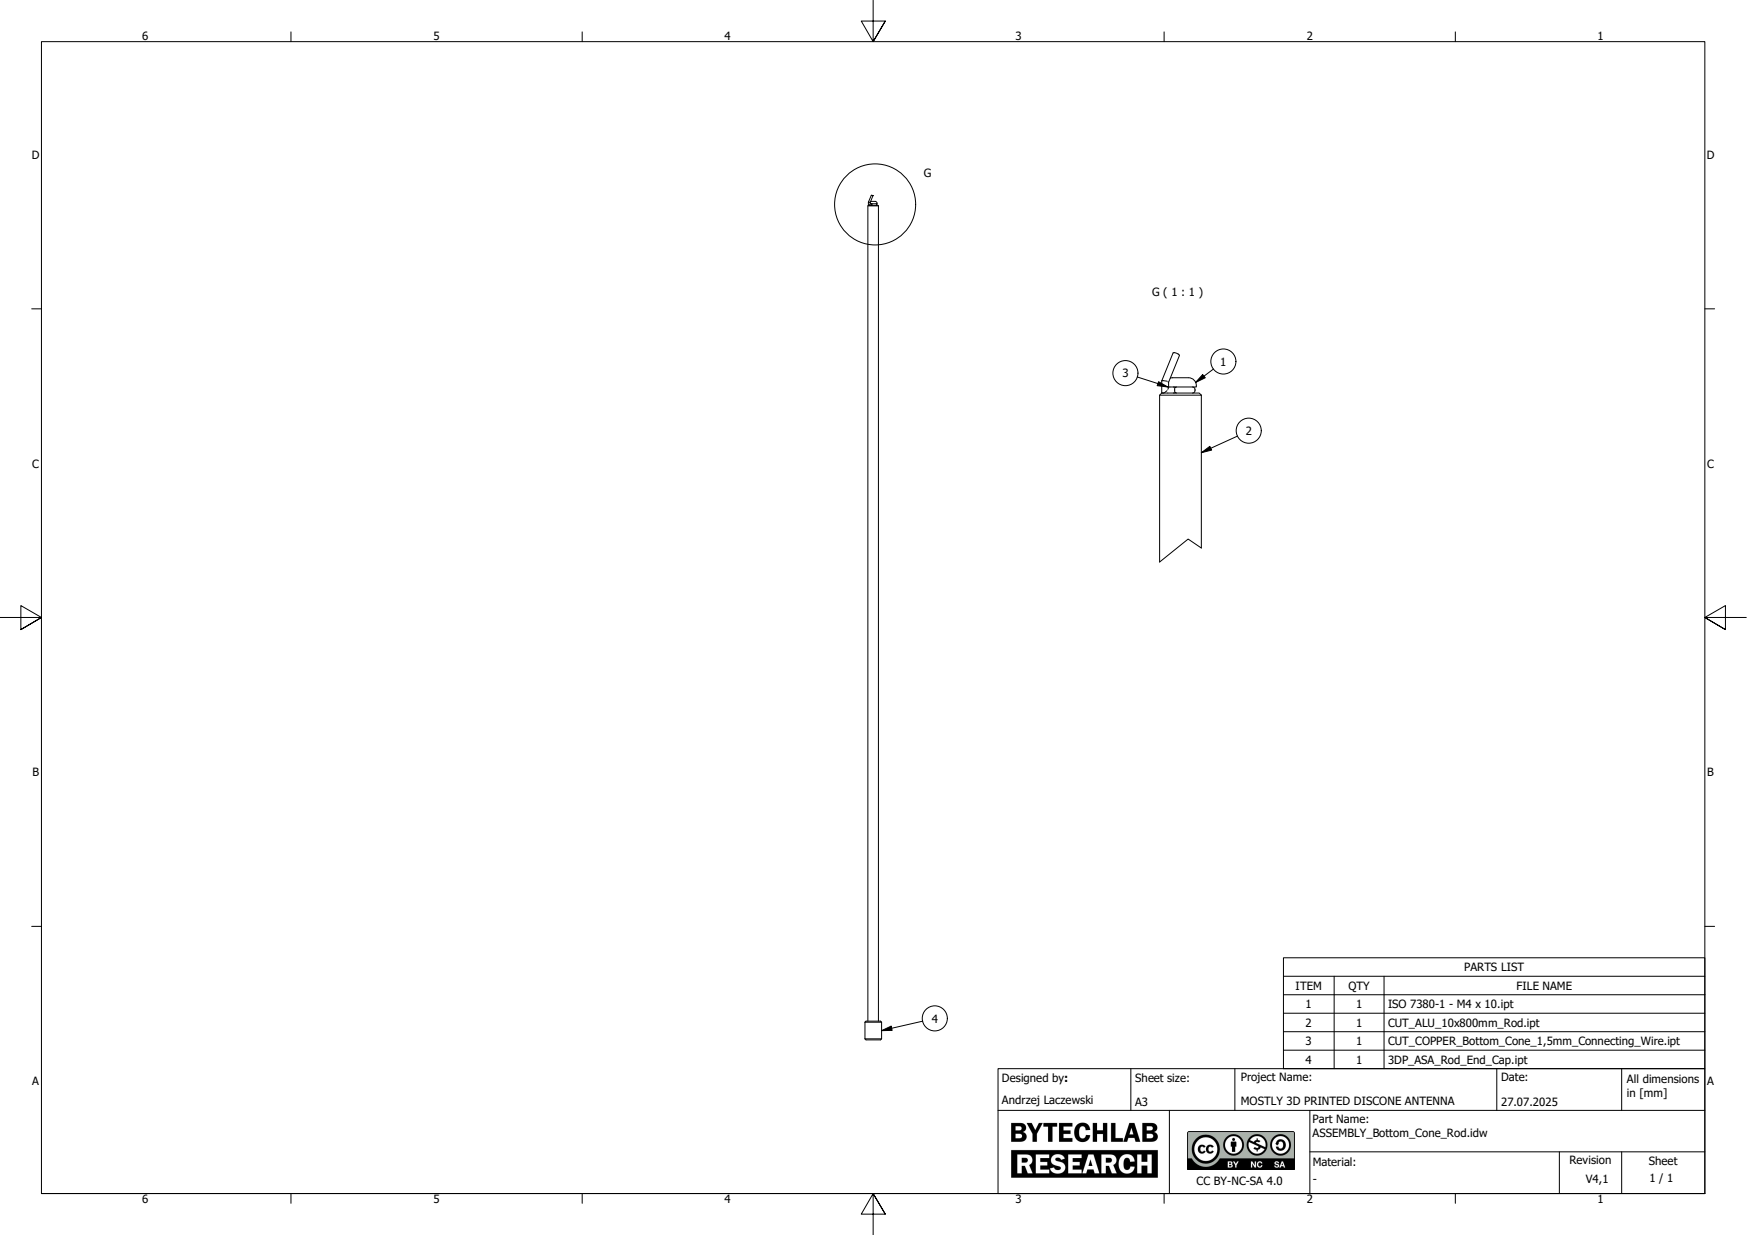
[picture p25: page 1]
PARTS LIST

ITEM | QTY | FILE NAME
1 | 1 | ISO 7380-1 - M4 x 10.ipt
2 | 1 | CUT_ALU_10x800mm_Rod.ipt
3 | 1 | CUT_COPPER_Bottom_Cone_1,5mm_Connecting_Wire.ipt
4 | 1 | 3DP_ASA_Rod_End_Cap.ipt

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

CC BY-NC-SA 4.0 | Part Name: ASSEMBLY_Bottom_Cone_Rod.idw

Material: - V4,1 | Revision | Sheet 1 / 1

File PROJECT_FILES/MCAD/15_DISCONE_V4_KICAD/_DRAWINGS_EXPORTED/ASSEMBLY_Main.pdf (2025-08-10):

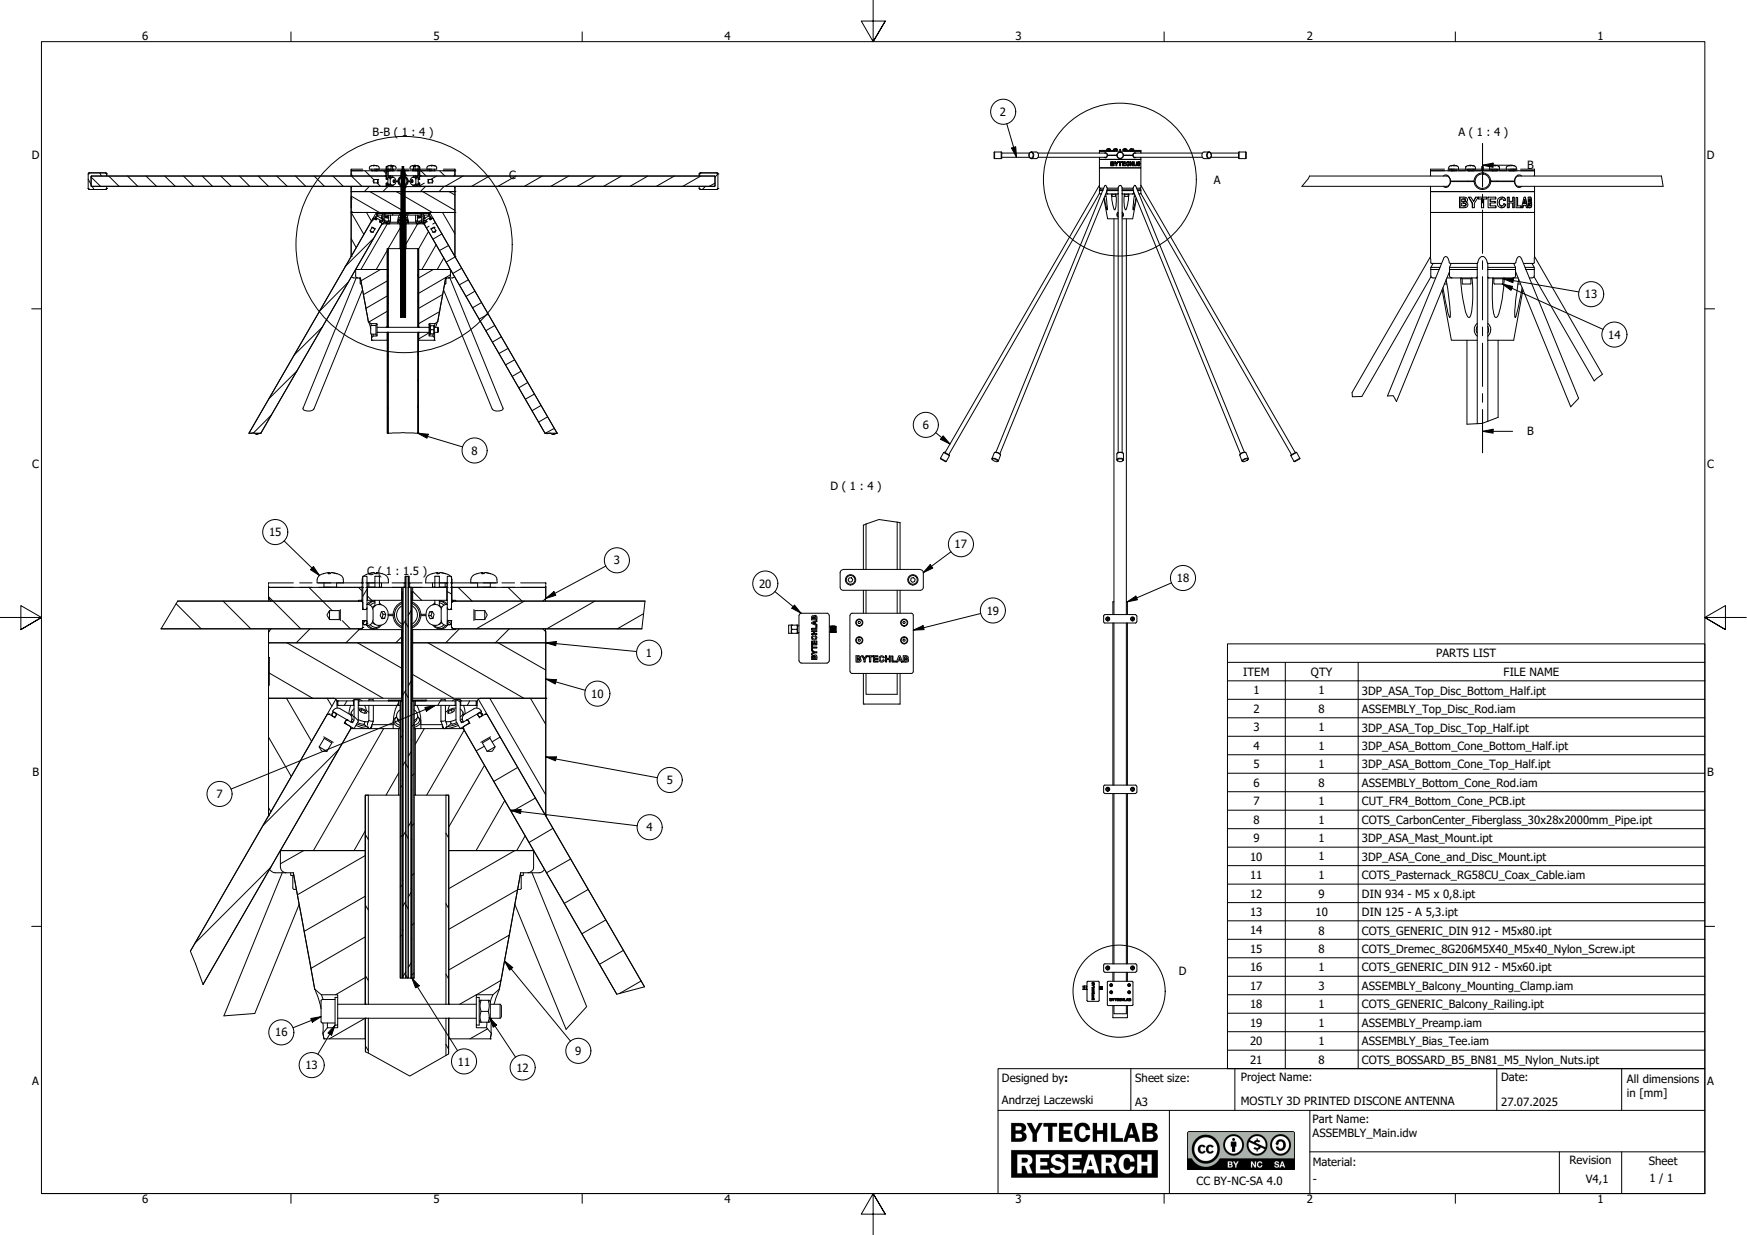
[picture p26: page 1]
PARTS LIST

ITEM | QTY | FILE NAME
1 | 1 | 3DP_ASA_Top_Disc_Bottom_Half.ipt
2 | 8 | ASSEMBLY_Top_Disc_Rod.iam
3 | 1 | 3DP_ASA_Top_Disc_Top_Half.ipt
4 | 1 | 3DP_ASA_Bottom_Cone_Bottom_Half.ipt
5 | 1 | 3DP_ASA_Bottom_Cone_Top_Half.ipt
6 | 8 | ASSEMBLY_Bottom_Cone_Rod.iam
7 | 1 | CUT_FR4_Bottom_Cone_PCB.ipt
8 | 1 | COTS_CarbonCenter_Fiberglass_30x28x2000mm_Pipe.ipt
9 | 1 | 3DP_ASA_Mast_Mount.ipt
10 | 1 | 3DP_ASA_Cone_and_Disc_Mount.ipt
11 | 1 | COTS_Pasternack_RG58CU_Coax_Cable.iam
12 | 9 | DIN 934 - M5 x 0,8.ipt
13 | 10 | DIN 125 - A 5,3.ipt
14 | 8 | COTS_GENERIC_DIN 912 - M5x80.ipt
15 | 8 | COTS_Dremec_8G206M5X40_M5x40_Nylon_Screw.ipt
16 | 1 | COTS_GENERIC_DIN 912 - M5x60.ipt
17 | 3 | ASSEMBLY_Balcony_Mounting_Clamp.iam
18 | 1 | COTS_GENERIC_Balcony_Railing.ipt
19 | 1 | ASSEMBLY_Preamp.iam
20 | 1 | ASSEMBLY_Bias_Tee.iam
21 | 8 | COTS_BOSSARD_B5_BN81_M5_Nylon_Nuts.ipt

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

CC BY-NC-SA 4.0 | Part Name: ASSEMBLY_Main.idw

Material: - V4,1 | Revision | Sheet 1 / 1

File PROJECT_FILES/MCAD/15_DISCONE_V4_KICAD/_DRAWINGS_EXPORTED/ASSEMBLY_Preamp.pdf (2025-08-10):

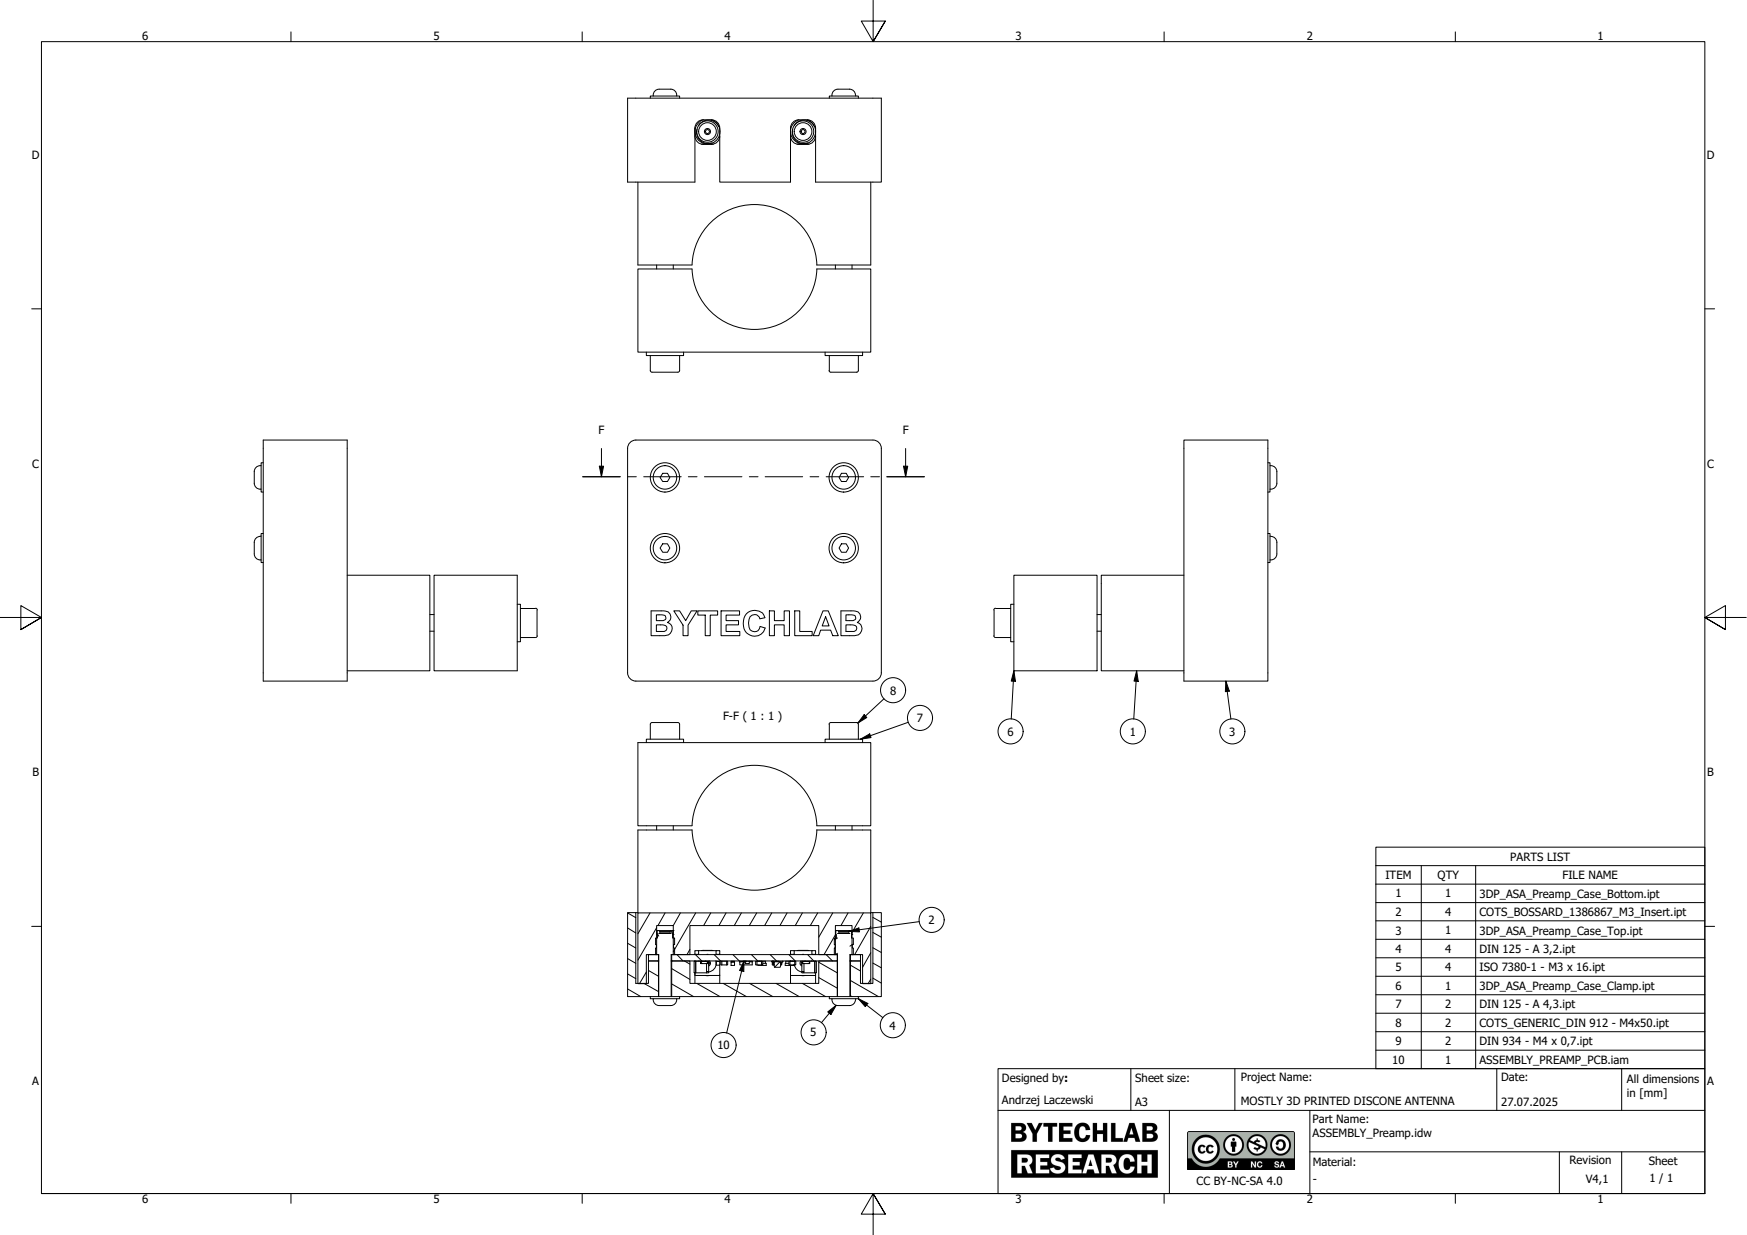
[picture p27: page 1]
PARTS LIST

ITEM | QTY | FILE NAME
1 | 1 | 3DP_ASA_Preamp_Case_Bottom.ipt
2 | 4 | COTS_BOSSARD_1386867_M3_Insert.ipt
3 | 1 | 3DP_ASA_Preamp_Case_Top.ipt
4 | 4 | DIN 125 - A 3,2.ipt
5 | 4 | ISO 7380-1 - M3 x 16.ipt
6 | 1 | 3DP_ASA_Preamp_Case_Clamp.ipt
7 | 2 | DIN 125 - A 4,3.ipt
8 | 2 | COTS_GENERIC_DIN 912 - M4x50.ipt
9 | 2 | DIN 934 - M4 x 0,7.ipt
10 | 1 | ASSEMBLY_PREAMP_PCB.iam

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

CC BY-NC-SA 4.0 | Part Name: ASSEMBLY_Preamp.idw

Material: - V4,1 | Revision | Sheet 1 / 1

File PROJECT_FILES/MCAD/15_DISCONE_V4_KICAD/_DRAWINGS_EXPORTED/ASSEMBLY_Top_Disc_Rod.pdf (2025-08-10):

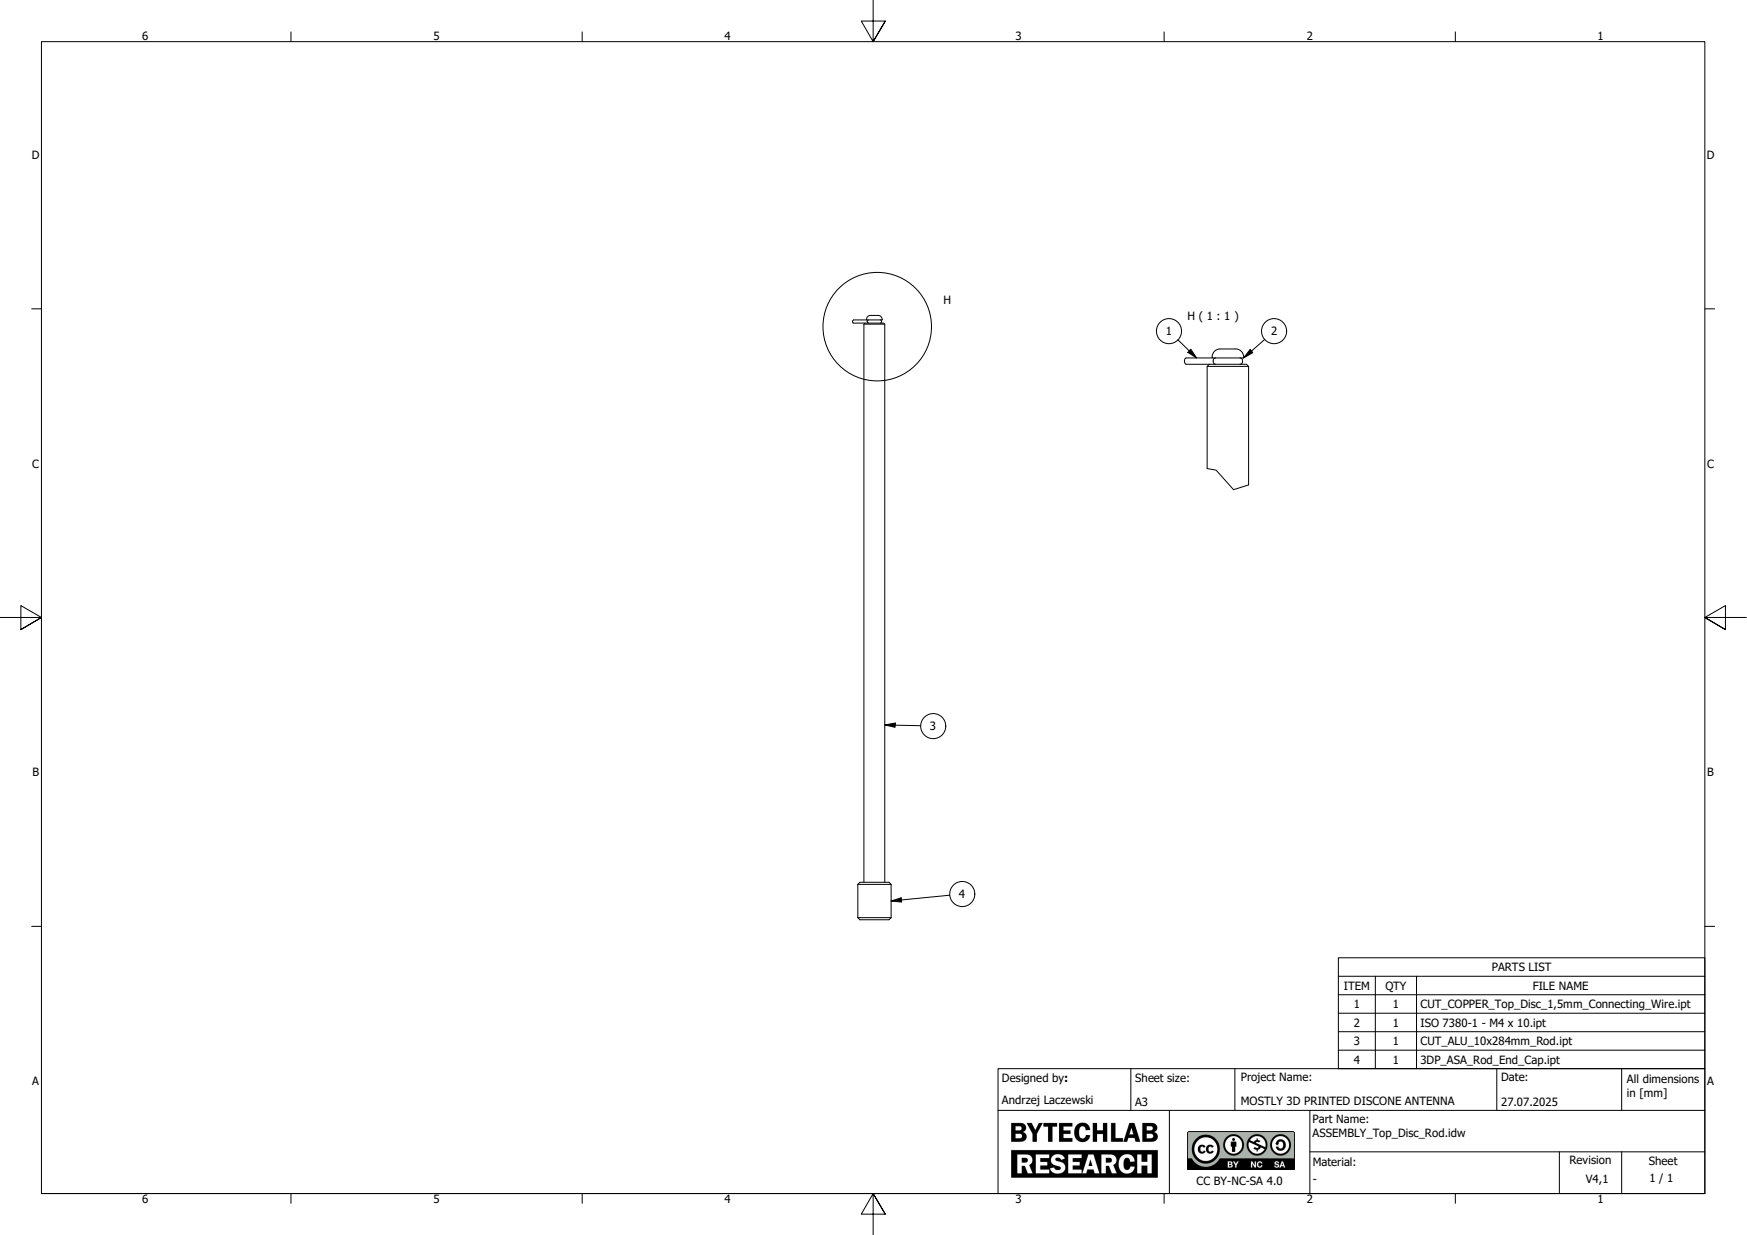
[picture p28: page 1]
PARTS LIST

ITEM | QTY | FILE NAME
1 | 1 | CUT_COPPER_Top_Disc_1,5mm_Connecting_Wire.ipt
2 | 1 | ISO 7380-1 - M4 x 10.ipt
3 | 1 | CUT_ALU_10x284mm_Rod.ipt
4 | 1 | 3DP_ASA_Rod_End_Cap.ipt

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

CC BY-NC-SA 4.0 | Part Name: ASSEMBLY_Top_Disc_Rod.idw

Material: - V4,1 | Revision | Sheet 1 / 1

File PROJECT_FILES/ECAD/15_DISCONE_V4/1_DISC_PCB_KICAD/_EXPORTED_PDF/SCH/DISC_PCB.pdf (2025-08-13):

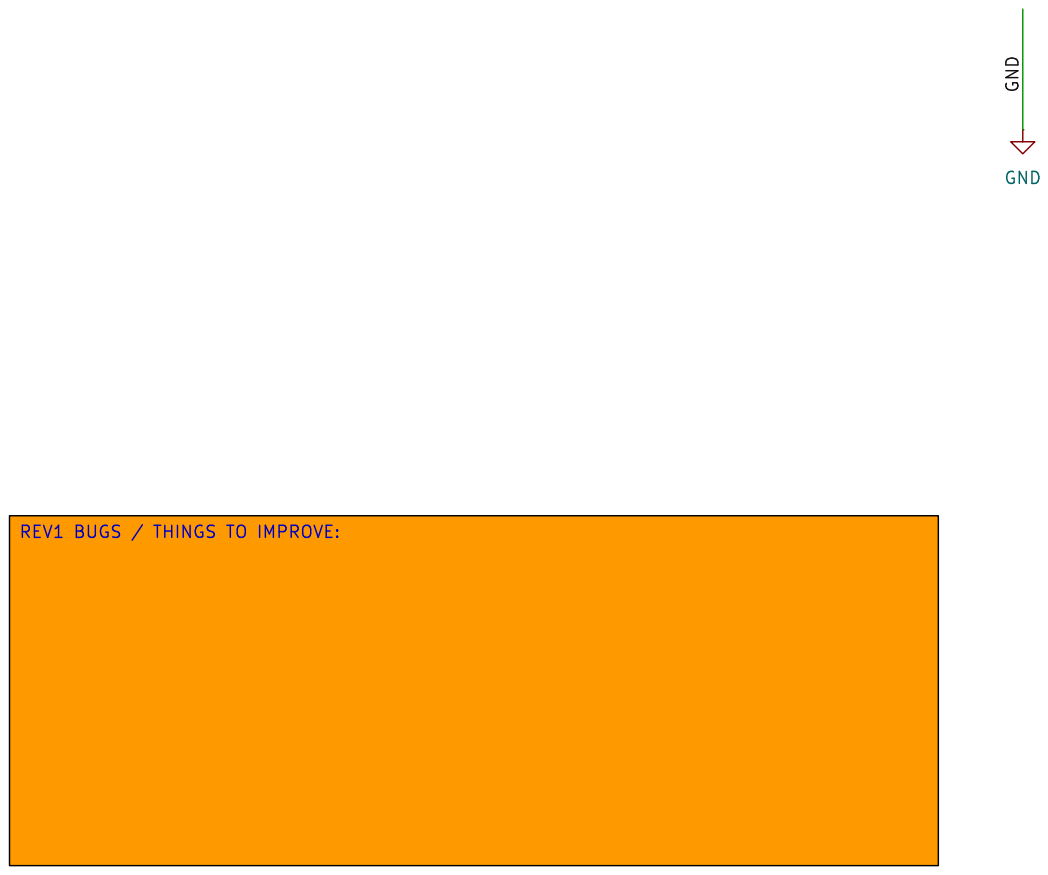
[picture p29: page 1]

REV1 BUGS / THINGS TO IMPROVE:

Project Name: Mostly 3D Printed Discone Antenna

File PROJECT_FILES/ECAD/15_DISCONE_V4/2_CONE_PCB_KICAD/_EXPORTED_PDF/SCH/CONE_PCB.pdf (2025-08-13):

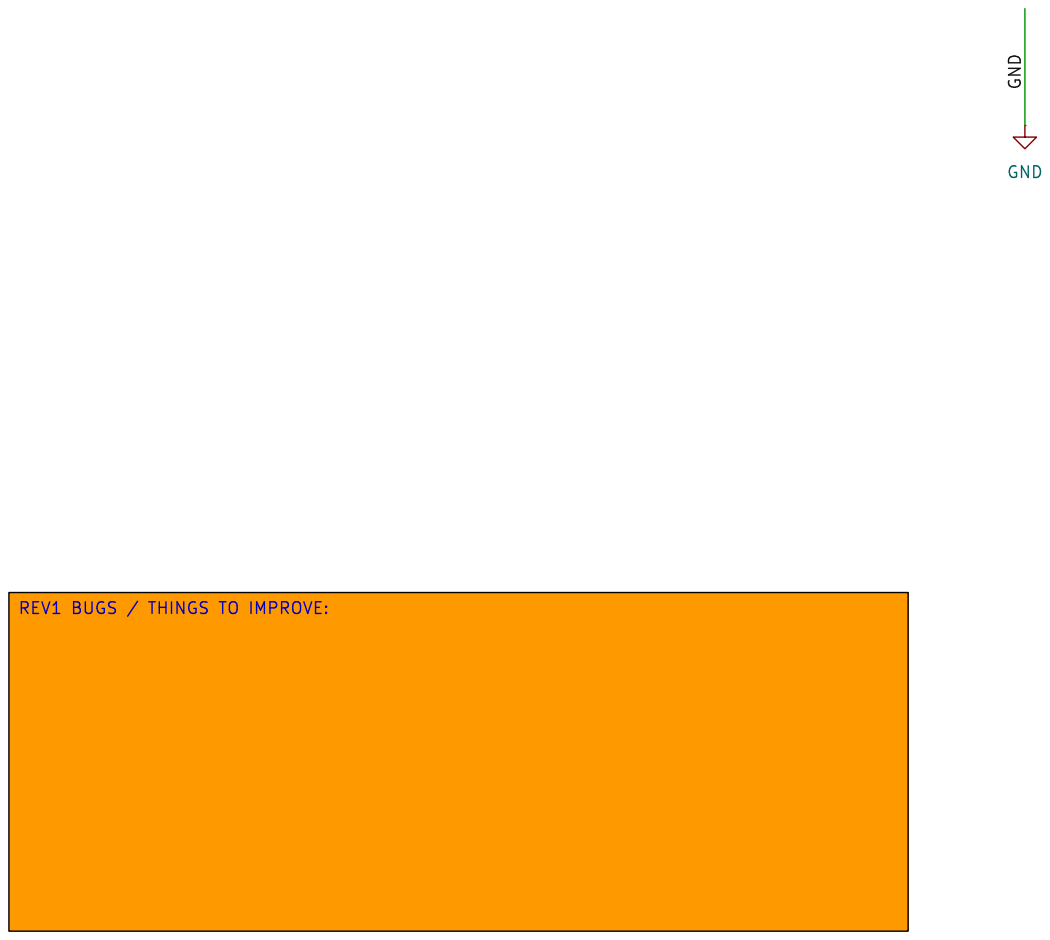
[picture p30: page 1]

REV1 BUGS / THINGS TO IMPROVE:

Project Name: Mostly 3D Printed Discone Antenna

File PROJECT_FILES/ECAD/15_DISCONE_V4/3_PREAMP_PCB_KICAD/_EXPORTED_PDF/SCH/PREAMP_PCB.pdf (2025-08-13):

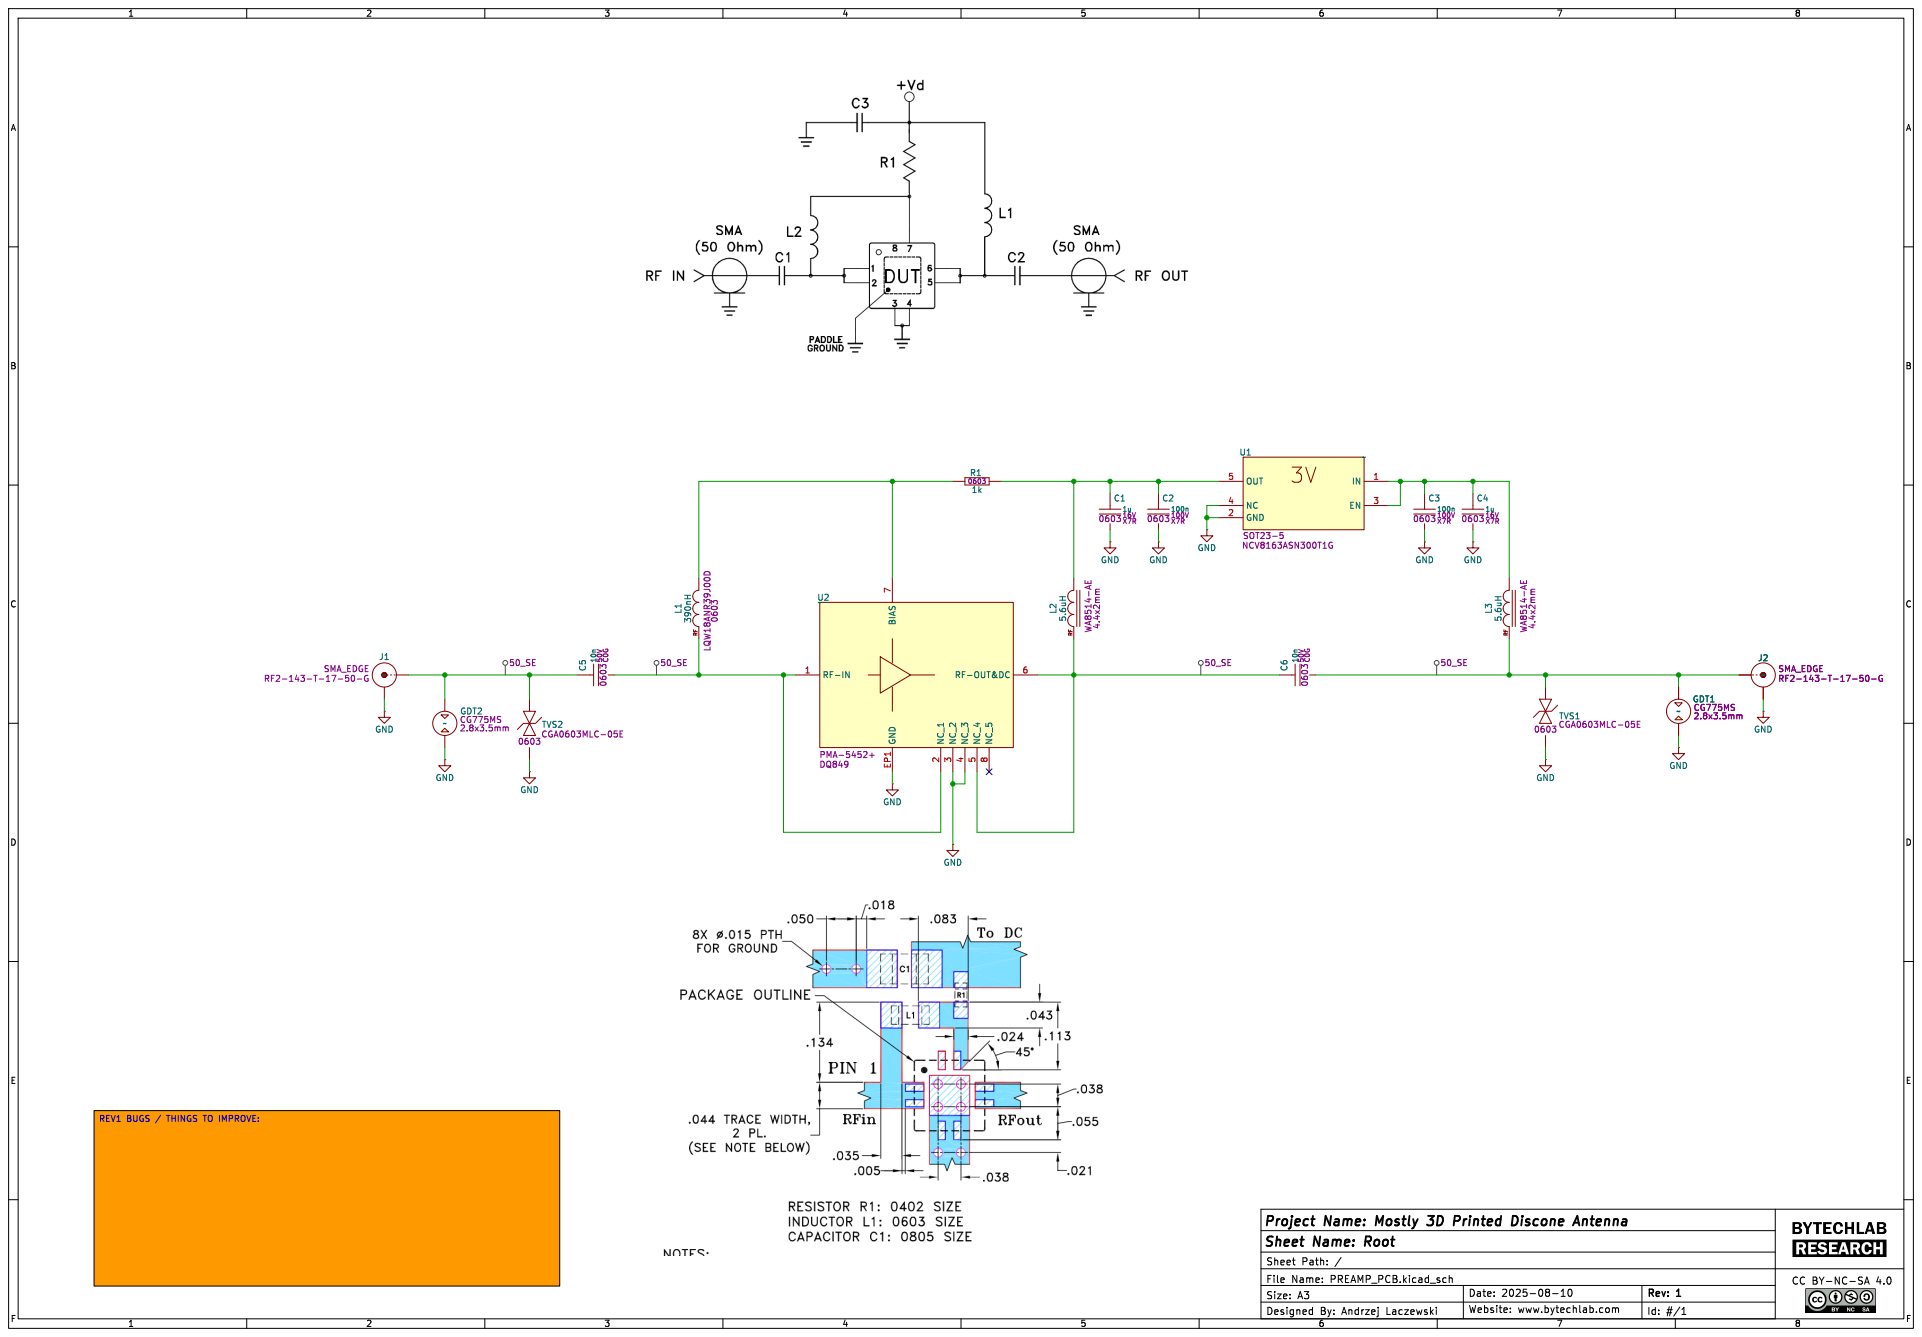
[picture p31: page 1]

8 RF-OUT&DC 6 U2~DQ849 PMA-5452+ GND GDT1 ~

Project Name: Mostly 3D Printed Discone Antenna C510n 0603 50V C0G

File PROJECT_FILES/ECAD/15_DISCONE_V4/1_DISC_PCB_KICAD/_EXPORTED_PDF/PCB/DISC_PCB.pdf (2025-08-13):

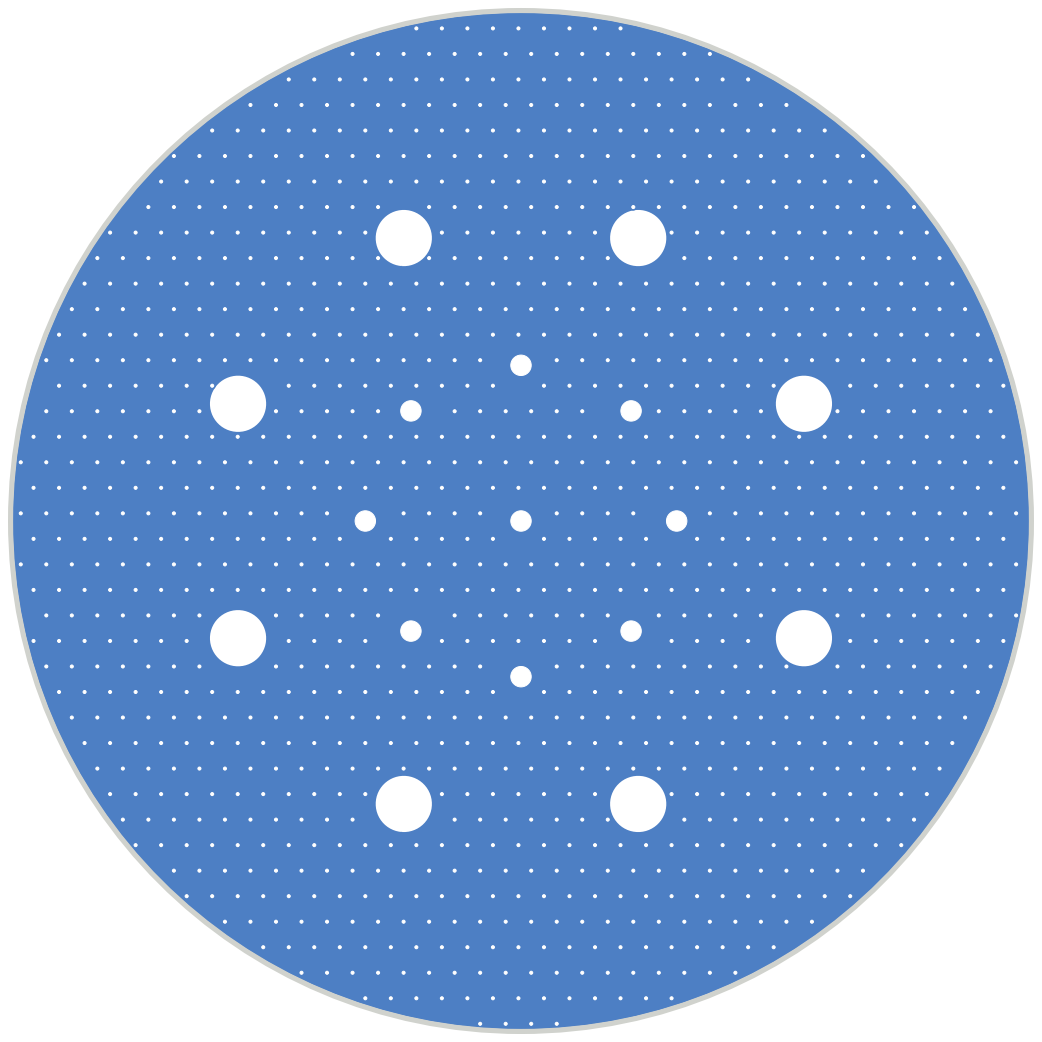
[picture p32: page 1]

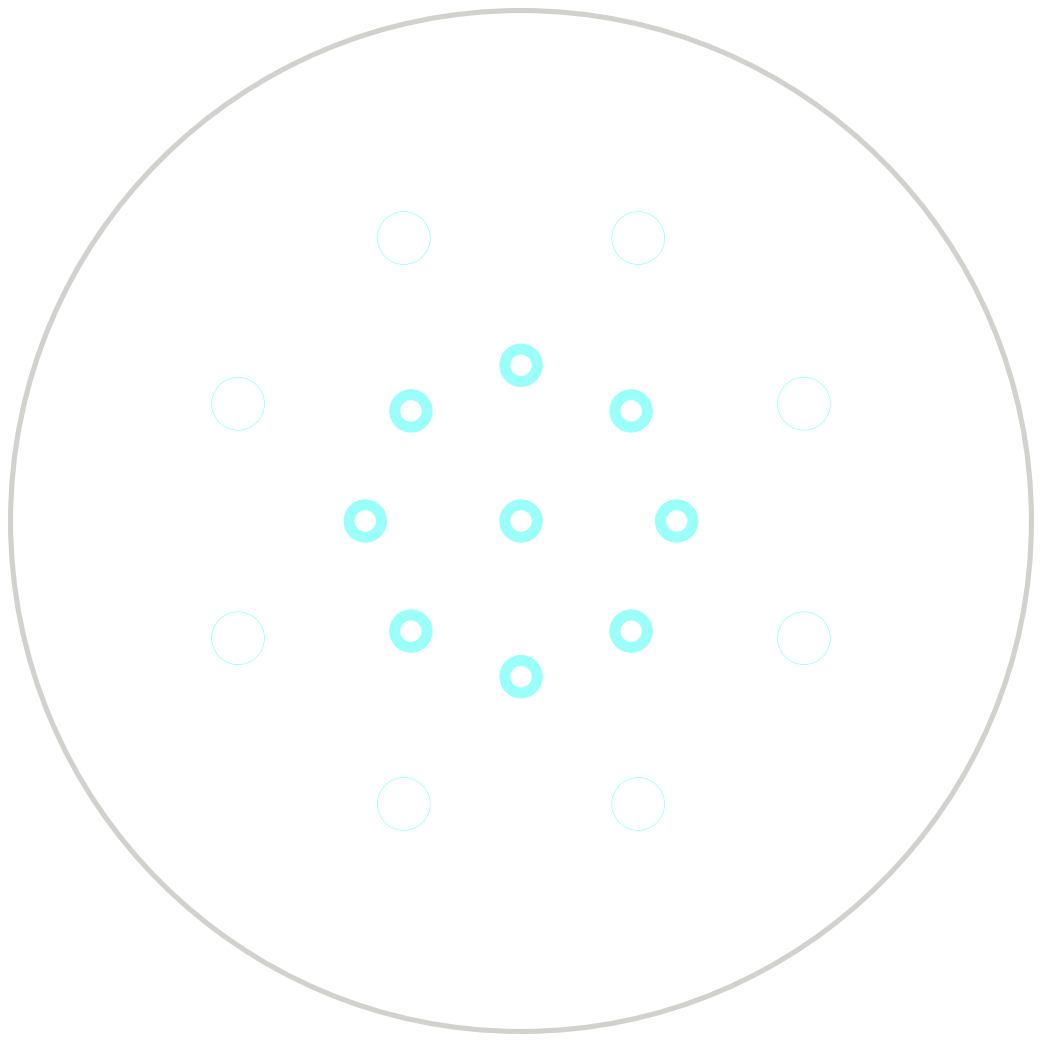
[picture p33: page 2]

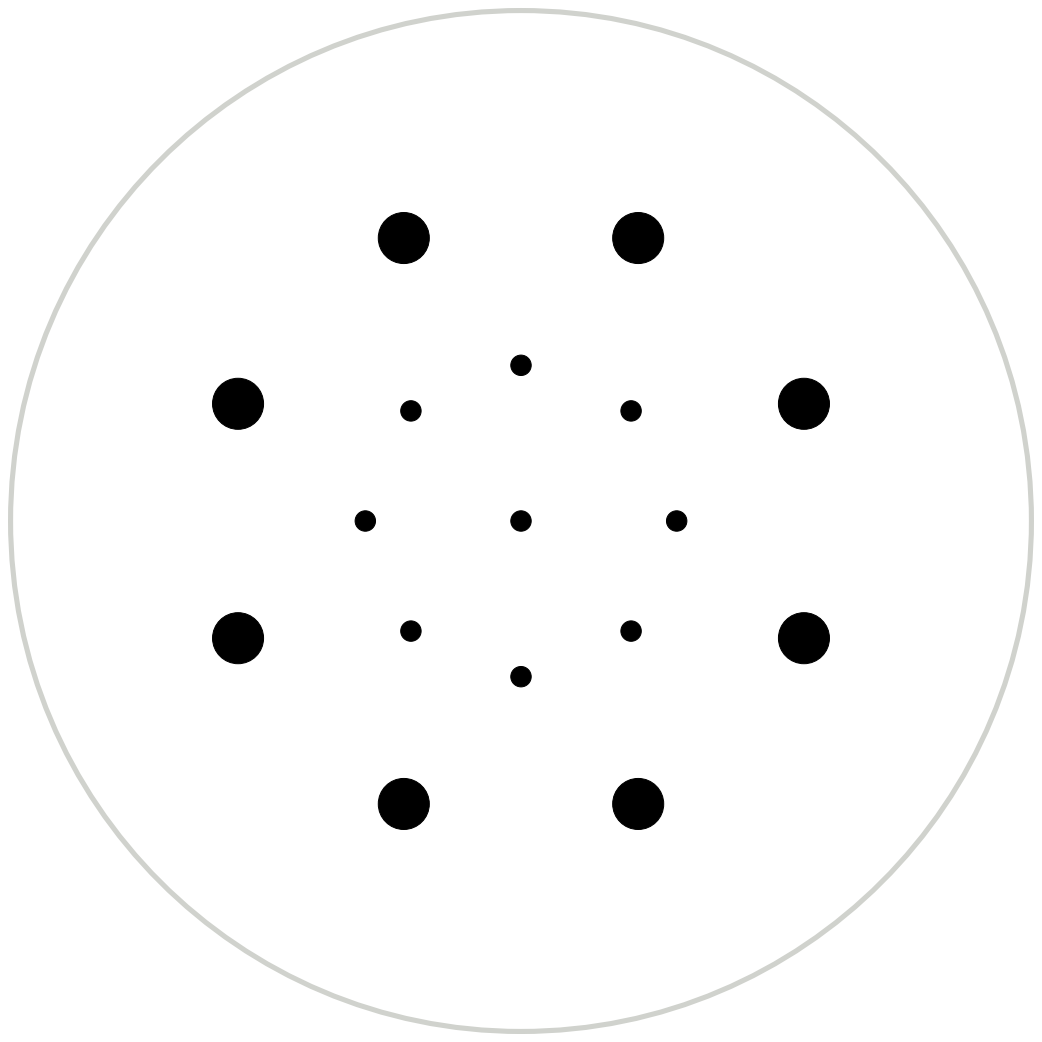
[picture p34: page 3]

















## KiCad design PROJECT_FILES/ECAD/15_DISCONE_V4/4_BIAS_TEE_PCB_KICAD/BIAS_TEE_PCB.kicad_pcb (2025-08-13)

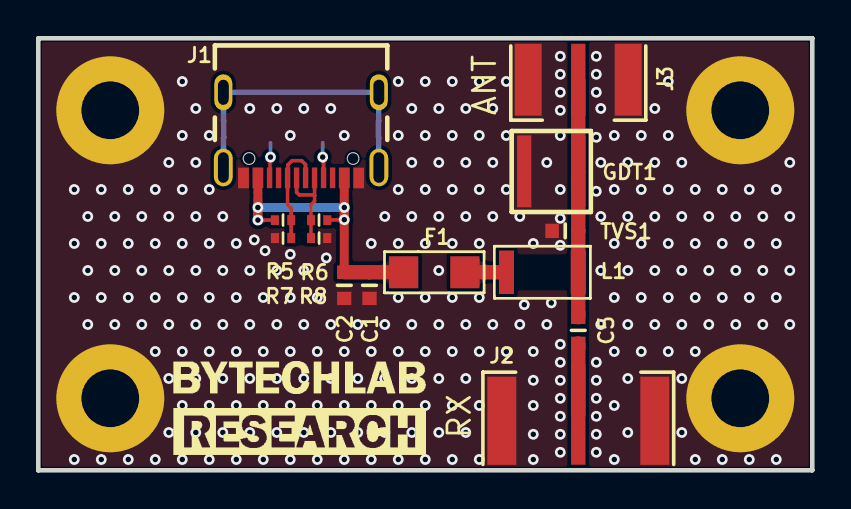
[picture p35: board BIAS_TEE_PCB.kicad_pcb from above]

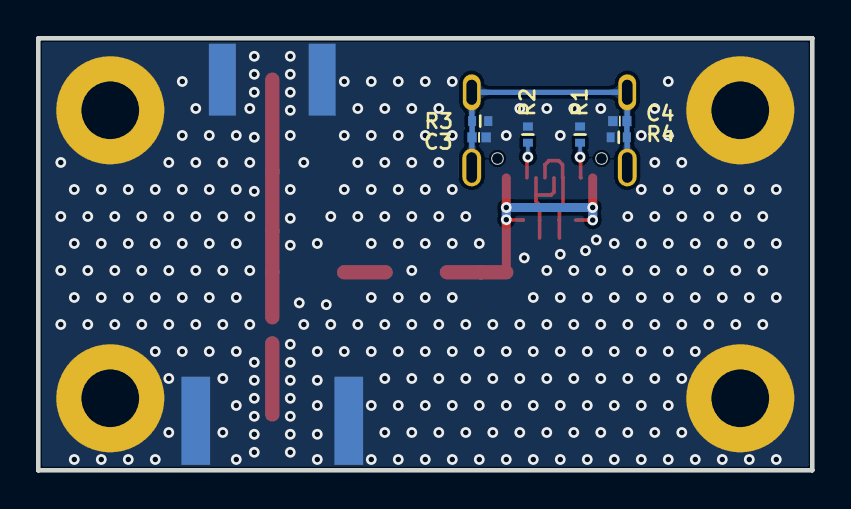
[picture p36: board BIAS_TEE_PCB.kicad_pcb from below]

Board: 2 copper layers, 43.0 x 24.0 mm, 20 parts (6 on the bottom side), 10 nets.

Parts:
C1: 100n; C_0603_1608
C2: 1u; C_0603_1608
C3, C4: 100n; C_0402_1005
C5: 10n; C_0603_1608
F1: F_250mA_24V_1206
GDT1: GDT_CG775MS
J1: J_USB_C_USB4105
J2: J_132366
J3: J_RF2-143-T-17-50-G
L1: 5.6uH; L_RF_5.6uH_4.4x2mm_WA8514-AE
R1, R2: 5.1k; R_0402_1005
R3, R4: 1M; R_0402_1005
R5, R6, R7, R8: NC; R_NC_0402_1005
TVS1: R_0603_1608

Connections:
GND: C1.2, C2.2, C3.2, C4.2, GDT1.2, J1.AB112 (GND), J1.BA112 (GND), J2.2 (GND), J3.2 (GND), R1.1, R2.1, R3.1, R4.1, R7.1, R8.1, TVS1.2
unnamed: C3.1, C4.1, J1.MH (GND), R3.2, R4.2
unnamed: F1.2, L1.2
unnamed: J1.A5 (CC1), R2.2
unnamed: J1.B5 (CC2), R1.2
unnamed: J1.A6 (D1+), J1.B6 (D2+), R5.1, R7.2
unnamed: J1.A7 (D1-), J1.B7 (D2-), R6.1, R8.2
unnamed: C5.2, J2.1 (X)
unnamed: C5.1, GDT1.1, J3.1 (X), L1.1, TVS1.1
VBUS: C1.1, C2.1, F1.1, J1.AB49 (VBUS), J1.BA49 (VBUS), R5.2, R6.2

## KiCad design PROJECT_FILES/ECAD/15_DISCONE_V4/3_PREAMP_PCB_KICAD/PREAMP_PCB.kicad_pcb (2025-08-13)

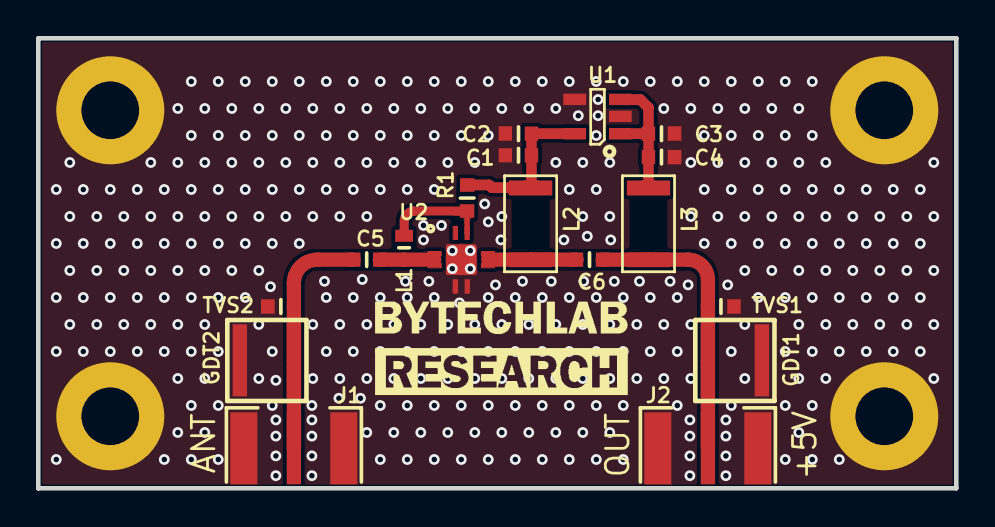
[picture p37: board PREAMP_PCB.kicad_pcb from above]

Board: 2 copper layers, 51.0 x 25.0 mm, 18 parts (0 on the bottom side), 8 nets.

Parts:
C1, C4: 1u; C_0603_1608
C2, C3: 100n; C_0603_1608
C5, C6: 10n; C_0603_1608
GDT1, GDT2: GDT_CG775MS
J1, J2: J_RF2-143-T-17-50-G
L1: 390nH; L_RF_390nH_0603_LQW18ANR39J00D
L2, L3: 5.6uH; L_RF_5.6uH_4.4x2mm_WA8514-AE
R1: 1k; R_0603_1608
TVS1, TVS2: R_0603_1608
U1: VL_NCV8163ASN300T1G
U2: U_PMA-5452+

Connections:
GND: C1.2, C2.2, C3.2, C4.2, GDT1.2, GDT2.2, J1.2 (GND), J2.2 (GND), TVS1.2, TVS2.2, U1.2 (GND), U1.4 (NC), U2.3 (NC_2), U2.4 (NC_3), U2.EP1 (GND)
unnamed: C5.1, GDT2.1, J1.1 (X), TVS2.1
unnamed: C6.2, GDT1.1, J2.1 (X), L3.1, TVS1.1
unnamed: C3.1, C4.1, L3.2, U1.1 (IN), U1.3 (EN)
unnamed: C1.1, C2.1, L2.2, R1.2, U1.5 (OUT)
unnamed: L1.2, R1.1, U2.7 (BIAS)
unnamed: C5.2, L1.1, U2.1 (RF-IN), U2.2 (NC_1)
unnamed: C6.1, L2.1, U2.5 (NC_4), U2.6 (RF-OUT&DC)

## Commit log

2025-08-10 Uplaod files
    [3DP_ASA_Balcony_Mounting_Clamp_Back.ipt, 3DP_ASA_Balcony_Mounting_Clamp_Back.stl, 3DP_ASA_Balcony_Mounting_Clamp_Front.ipt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]
2025-08-13 Update jobset & exported files
    [BIAS_TEE_PCB.kicad_pcb, BIAS_TEE_PCB.step, CONE_PCB.kicad_sch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]
